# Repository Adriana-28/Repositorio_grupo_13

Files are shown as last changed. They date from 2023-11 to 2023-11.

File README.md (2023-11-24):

<p align="center">
  
</p>

# 👋 Bienvenidos al repositorio del Grupo 13.

- Curso: Fundamentos de Biodiseño
- Línea de investigación: Biomecánica
- Proyecto: "Prótesis de manufactura digital del dedo pulgar"

## ✍️ Profesores del curso

- Renzo Jose Chan Ríos
- Juan Manuel Zuñiga Mamani
- Andrés Rodriguez De Velasco
- Shirley Pahuachon

## 👥 Integrantes del proyecto
  
| Integrantes | Rol del proyecto | Correo electrónico | Foto  |
| :---: | :---: | :---: | :-----: |
| Garcia Reyes Salet Carelis | Coordinadora de investigación  | salet.garcia@upch.pe | <image align="center;" style="borde-radius: 50%;" width="90px;" height="120px;" src="https://github.com/Adriana-28/Repositorio_grupo_13/blob/main/Im%C3%A1genes/WhatsApp%20Image%202023-09-21%20at%2022.54.08.jpeg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">
| Cerna Quispe Alessia Mercedes | Coordinadora de página web  | alessia.cerna@upch.pe | <image align="center;" style="border-radius: 50%;" width="90px;" src ="https://github.com/Adriana-28/Repositorio_grupo_13/blob/main/Im%C3%A1genes/Foto%20Alessia.jpeg?raw=true"> |
| Quispe Gomez Adriana Patricia  | Coordinadora de impresión 3D | adriana.quispe@upch.pe | <image align="center;" width="90px;" src="https://github.com/Adriana-28/Repositorio_grupo_13/blob/main/Im%C3%A1genes/WhatsApp%20Image%202023-09-21%20at%2013.15.54.jpeg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" >
| Panez Cuizano Rafael Alonso | Coordinador de programación | rafael.panez@upch.pe | <image align="center;" style="borde-radius: 50%;" width="90px;" height="120px;" src="https://github.com/Adriana-28/Repositorio_grupo_13/blob/main/Im%C3%A1genes/WhatsApp%20Image%202023-09-21%20at%2022.51.50.jpeg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">
| Munayco Saravia Diego Fabrizio | Coordinador de diseño 3D | diego.munayco@upch.pe | <image align="center;" style="borde-radius: 50%;" width="90px;" src="https://github.com/Adriana-28/Repositorio_grupo_13/blob/main/Im%C3%A1genes/WhatsApp%20Image%202023-09-21%20at%2020.53.01.jpeg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">
| Peralta Yauyo Franco Pedro Sebastian | Coordinador de electrónica | franco.peralta@upch.pe | <image align="center;" style="borde-radius: 50%;" width="90px;" src="https://github.com/Adriana-28/Repositorio_grupo_13/blob/main/Im%C3%A1genes/WhatsApp%20Image%202023-09-21%20at%2022.50.15.jpeg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">

## Contexto

Las lesiones de la mano representan el 12% de todas las lesiones traumáticas en EE.UU., muchas de las cuales consisten en amputaciones traumáticas de los dedos. En 2022, en Estados Unidos se produjeron más de 3.300 amputaciones del pulgar, las cuales se asocian con preocupaciones sociales para el paciente, deterioro funcional y considerables consecuencias económicas para la comunidad atribuidas al absentismo del paciente y a la pérdida de empleo [1]. Esto debido a que el pulgar representa alrededor del 40% de la función de la mano; por lo tanto, perderlo supondría importantes costes médicos, hospitalarios y sociales [2].
En Brasil, este tipo de lesiones son más frecuentes en hombres de entre 20 y 45 años. En términos de prevalencia, la amputación del dedo índice es la más frecuente, con un 28%, seguida del dedo corazón, con un 24%, el anular, con un 21%, el meñique, con un 14%, y el pulgar, con un 13%.” [3].

En Perú, el Instituto Nacional de Rehabilitación define a las limitaciones de la destreza como problemas que se presentan en actividades que se realizan con las manos y dedos, como manipular, abrir y cerrar puertas o ventanas [4], asimismo, el Consejo Nacional para la Integración de la Persona con Discapacidad, informó que el 80,6% de las personas inscritas en el Registro Nacional de la Persona con Discapacidad presenta limitaciones de la destreza [5]. A partir de lo anterior, se puede identificar la relevancia del porcentaje de personas que no pueden realizar actividades cotidianas, incluso la preocupación de estas cifras aumenta, pues el ministerio de Trabajo y Promoción del Empleo a través de "Notificaciones de accidentes de trabajo, incidentes peligrosos y enfermedades ocupacionales" reporta, hasta mayo del 2023, un total de 81 casos de amputaciones por accidentes de trabajo [Tabla 1] y, en promedio, el 16,62% fueron accidentes en los cuales, los dedos de la mano fueron afectados [Tabla 2]. 

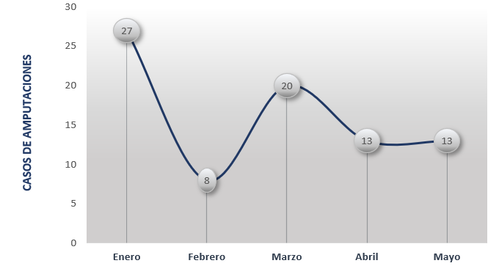
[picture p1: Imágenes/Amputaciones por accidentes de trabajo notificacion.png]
  

| Meses |  Enero  | Febrero | Marzo  | Abril | Mayo |
| :---: | :---: | :---: | :---: | :---: | :---: |
|  Cantidad de amputaciones  | 27  | 8 | 20 | 13  |  13 |

> Tabla 1. Notificaciones de amputaciones por accidentes de trabajo 2023. Fuente: Ministerio de Trabajo y Promoción del Empleo [18].

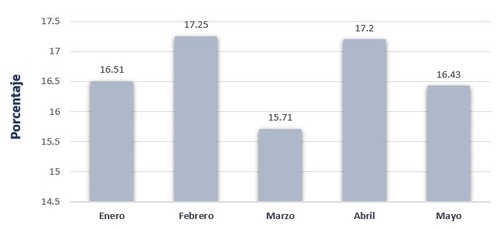
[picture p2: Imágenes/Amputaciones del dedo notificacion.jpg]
  

| Meses |  Enero  | Febrero | Marzo  | Abril | Mayo |
| :---: | :---: | :---: | :---: | :---: | :---: |
|  Porcentaje  |  16.51  |  17.25 |  15.71  |  17.2  |  16.43 |

> Tabla 2. Notificaciones del porcentaje de amputaciones de dedo de la mano 2023. Fuente: Ministerio de Trabajo y Promoción del Empleo [18].

## **👍 Anatomía del pulgar**

La anatomía del dedo pulgar presenta dos músculos principales:

- Dedo extensor largo: El músculo extensor largo del pulgar es crucial para realizar varios movimientos en la mano y el antebrazo. Extiende y abduce el pulgar, ayuda en la aducción, y en ocasiones contribuye a la supinación. Su función es esencial para actividades que requieren movimientos precisos de la mano y el pulgar. 

- Dedo extensor corto: El músculo oponente del pulgar es responsable de realizar movimientos complejos del pulgar conocidos como "oposición". En estos movimientos, el primer metacarpiano se desplaza hacia adelante y hacia el centro en un arco que involucra abducción, rotación medial, flexión y abducción del pulgar en la articulación carpometacarpiana. Esto es fundamental ya que permite que la yema del pulgar pueda tocarse con la yema de los demás dedos, lo que habilita la ejecución de acciones precisas con la mano. 

Los músculos interóseos dorsales tienen la función de abducir los dedos índice, corazón y anular. El primer músculo interóseo dorsal es responsable de rotar el índice en la articulación metacarpo-falángica y ocasionalmente colabora con el músculo aductor del pulgar en la aducción del pulgar. Debido a sus inserciones en la expansión dorsal de los dedos, estos músculos, al igual que los músculos interóseos palmares, ayudan a los músculos lumbricales a facilitar los movimientos de flexión y extensión en las articulaciones metacarpofalángicas e interfalángicas de los dedos. [6]

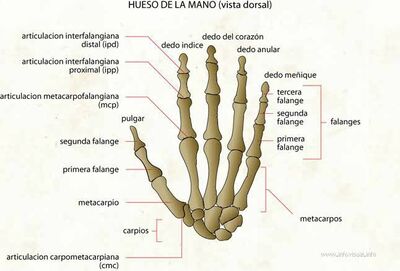
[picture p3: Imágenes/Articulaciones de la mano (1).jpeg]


> Figura 1. Huesos y articulaciones de la mano. Fuente: Rehabilitation of the Hand and Upper Extremity [6].

Según el Departamento de Ortopedia y Traumatología del Hospital Clínico La Florida, Santiago, Chile, la importancia del dedo pulgares que al estar en posición de oposición nos permite realizar distintos tipos de pinza, como las pinzas bidigitales por oposición del pulgar con la parte terminal, subterminal o subterminolateral de los dedos, pinzas pluridigitales terminoterminal o pinza digitopalmar o palmar cilíndrica entre otras. La amputación del pulgar repercute muy negativamente en la función de la mano afectando hasta en un 40-50% y disminuyendo en un 20% la fuerza de puño y pinza. Para obtener un pulgar funcional se requiere que este sea sensible y que sea oponible, y para esto es fundamental que sea estable, fuerte y móvil y además preservar su largo, al menos distal a la parte proximal de la articulación interfalángica [7]

------------

## ✋ Agarres de la mano

Un agarre es toda posición estática de la mano con un objeto que puede ser sujetado firmemente por esta [8]. Se han clasificado alrededor de 16-17 agarres específicos de la mano [9]. Se pueden distinguir alrededor de cuatro categorías generales: [10]

- Poder: Utiliza la mano y los dedos en forma de empuñadura incrementando así la fuerza del agarre en un objeto.
- Precisión:  Involucra el uso del dedo pulgar y la yema de los dedos restantes. Ayuda a manipular objetos de forma exacta.  
- Intermedio: Agarre donde se emplea el dedo índice, pulgar y de apoyo la palma de la mano. Comprenden acciones que necesitan poder y precisión.  
- No prensil: Agarre de objetos sin involucrar la manipulación de los dedos en forma prensil.

Existen 6-9 agarres aproximadamente se utilizan para cerca del 80% de las actividades de la vida diaria e industrial [9] [11]. En general, incluyen variaciones de movimientos como los siguientes: Agarre cilíndrico, agarre intermedio, agarre de gancho, pinza de dos dedos, pinza lateral, pinza de tres dedos, agarre no prensil, agarre lumbrical, agarre oblicuo y agarre intermedio de poder-precisión representan alrededor de 97% variaciones de agarres de la mano encontradas. [12] [9]

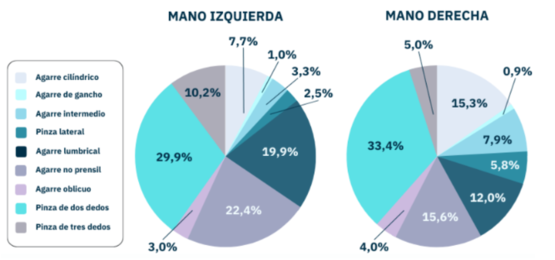
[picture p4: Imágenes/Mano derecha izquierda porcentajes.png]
 
 
> Figura 2. Porcentaje de los tipos de agarres de la mano derecha e izquierda. Fuente: Relevance of grasp types to assess functionality for personal autonomy [12].

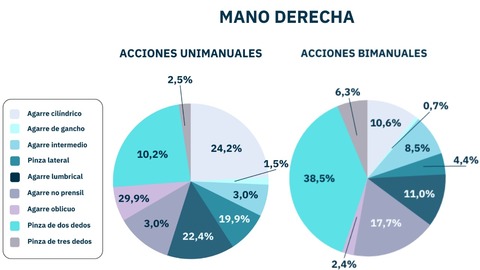
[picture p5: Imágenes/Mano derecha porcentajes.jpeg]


> Figura 3. Porcentaje de las acciones unimanuales y bimanuales de la mano derecha. Fuente: Relevance of grasp types to assess functionality for personal autonomy [12].

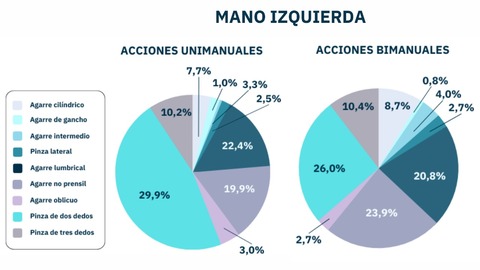
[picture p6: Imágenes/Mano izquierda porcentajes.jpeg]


> Figura 4. Porcentaje de las acciones unimanuales y bimanuales de la mano izquierda. Fuente: Relevance of grasp types to assess functionality for personal autonomy [12].

Siendo el movimiento de pinza de dos dedos el de mayor frecuencia. Cabe indicar que el estudio seleccionó alrededor de 128 tareas, que incluyen áreas como movilidad, comunicación, autocuidado, vida social y actividades domésticas. 

## ¿Cuál es la problemática?

¿Cómo podríamos mejorar el movimiento de pinza en una prótesis 3D del dedo pulgar?

## 💡 Propuesta de solución:

“Prótesis 3D de dedo pulgar con micromotores y componentes para utilizar señales mioeléctricas de músculos cercanos y realizar un agarre de pinza más preciso.”

## Propuesta de valor

El elastómero es uno de los componentes principales que diferencian a nuestro dedo protésico de los otros presentes en el mercado, ya que brindará flexibilidad al momento de generar el agarre pinza, asimismo, los resortes brindan la función de flexión cuando los hilos tensores se muevan debido a la rotación de los servomotores y genera el retorno del dedo a su estado inicial.

## Conoce más acerca de nuestro proyecto

[**Repositorio grupo 13**](https://github.com/Adriana-28/Repositorio_grupo_13/blob/main/Documentaci%C3%B3n/Entregables/ENTREGABLES.md)

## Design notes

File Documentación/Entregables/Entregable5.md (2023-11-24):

# Quinto entregable

## Modelado 3D

[**Link del modelado de la prótesis en OnShape**](https://cad.onshape.com/documents/16cc39156ec121ca3a5e2af5/w/de0ad5fc317e40029288b729/e/4e24d986928bb4f646aaed63)

### Dedo pulgar

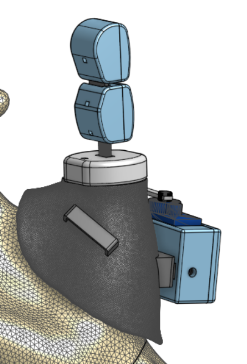
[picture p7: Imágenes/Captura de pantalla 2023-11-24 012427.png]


#### Planos

[**Planos del dedo pulgar en OnShape**](https://cad.onshape.com/documents/16cc39156ec121ca3a5e2af5/w/de0ad5fc317e40029288b729/e/6d90e9a6181cf063c8d92964)

### Case de los servomotores

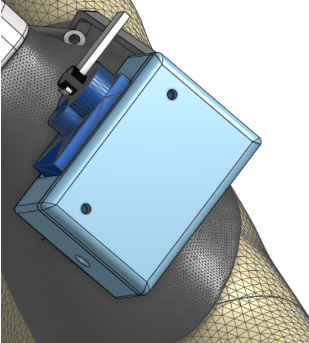
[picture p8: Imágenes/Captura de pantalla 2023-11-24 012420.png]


#### Planos

[**Case de los servomotores**](https://github.com/Adriana-28/Repositorio_grupo_13/blob/main/Im%C3%A1genes/WhatsApp%20Image%202023-11-03%20at%2002.50.40.jpeg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)

### Case del sensor EMG

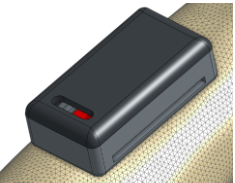
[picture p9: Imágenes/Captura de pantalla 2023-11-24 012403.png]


#### Planos

[**Case del sensor en OnShape**](https://github.com/Adriana-28/Repositorio_grupo_13/blob/main/Im%C3%A1genes/WhatsApp%20Image%202023-11-03%20at%2002.51.05.jpeg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)

### Caja de los componentes

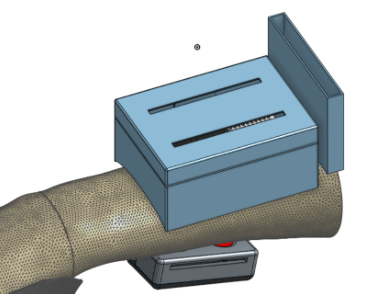
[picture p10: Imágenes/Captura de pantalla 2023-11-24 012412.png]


#### Planos

[**Caja de los componentes**](https://github.com/Adriana-28/Repositorio_grupo_13/blob/main/Im%C3%A1genes/WhatsApp%20Image%202023-11-03%20at%2002.50.23.jpeg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)

## Esquema electrónico

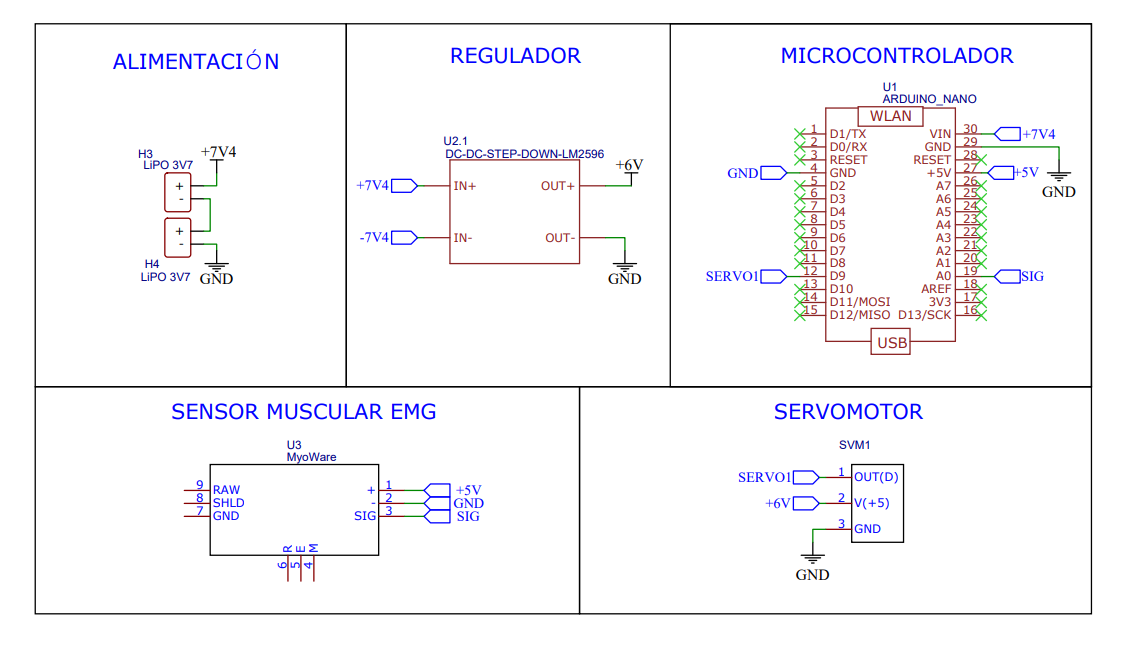
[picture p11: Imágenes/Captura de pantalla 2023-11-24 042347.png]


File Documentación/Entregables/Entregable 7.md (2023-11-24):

# Séptimo entregable

## Código del proyecto

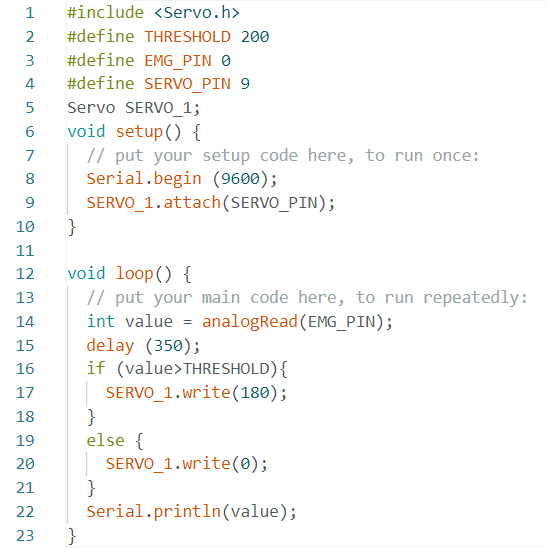
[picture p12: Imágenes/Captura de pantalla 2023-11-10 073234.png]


**- Descripción del código:**

Se demuestra un funcionamiento óptimo del código Arduino. Inicia mediante la instalación de la librería Servo y la creación de variables globales [THRESHOLD,EMG_PIN,SERVO_PIN,SERPO_PIN2]. Luego de la activación del comando serial, conectamos los dos servomotores con sus respectivos pines analogicos, y mediante la función analogRead obtenemos los valores de las señales musculares detectadas por el sensor EMG. Finalmente, mediante una estructura condicional y la magnitud del valor obtenido ejecutamos el movimiento mediante los servomotores sea 180° cuando se ejerce presión y 0° cuando el músculo se encuentra relajado, obteniendo al mismo tiempo la lectura de la señal. 

## Lista de módulos identificados

**Lista de componentes presentes en el funcionamiento del código:**

- Módulo del Sensor EMG:
  
En este caso, este dispositivo cumple la función de monitorear las señales eléctricas de origen muscular, cumple el proceso de amplificar y filtrar para luego ser receptado por algún procesador [Arduino]. Esto se lleva a cabo mediante la lectura del valor analogica de la señal correspondiente al sensor EMG, esto apoyado de los electrodos, el cual al obtener un valor brindaría la acción necesaria para desencadenar el funcionamiento del servomotor y la lectura del EMG, dentro de ciertos parámetros que dependen netamente de la fuerza ejercida por el usuario.

- Módulo de los Servomotores:
  
Identificamos este dispositivo como una alternativa de mecanismo de movimiento, siendo más específicos, de rotación en un rango predeterminado, usualmente entre los 0-180 grados los cuales son utilizados en aplicaciones que requieran precisión y control. La biblioteca Servo nos brinda mayor facilidad mediante la implementación  de señales PWM [Modulación por ancho de pulso], y en nuestro caso dependiente de la señal recibida por el módulo anteriormente mencionado, afectará el rango del movimiento deseado. En este caso al mantener el músculo relajado el servomotor rotara en una posición equivalente a 0 grados y en caso detecte algún esfuerzo muscular generado por el usuario, el servomotor inmediatamente modificara su rango de posición a 180 grados aproximadamente.

## Funcionamiento del circuito con sensor EMG

[**Video del funcionamiento del circuito**](https://drive.google.com/drive/folders/12zblGr60froh0Lr7Ek2Yj1X8CRKrDT_y?usp=drive_link)

Descripción: Se muestra un correcto funcionamiento del circuito. Se utiliza una hoja de papel para la simulación de una superficie y verificar que esta se doble con la programación del circuito. El código corre en el arduino y el sensor EMG detecta las señales y adicionalmente las filtra. Luego, el arduino procesa los datos y envía la señal para que los servomotores giren acorde a lo indicado en el código. 

## Pruebas de prototipo

Debido a las características de nuestro producto, hemos decidido hacer pruebas múltiples con 3 tipos de elastómeros que varían en flexibilidad; sin embargo, todos son del mismo color y están hechos de TPU:

Elastómeros a utilizar:

- Elastómero 1: 2 líneas de pared, no tiene infill porque con esas líneas cubre todo debido a las dimensiones pequeñas de la pieza. Poco flexible. 

- Elastómero 2: 1 línea de pared y 0% de infill. Bastante flexible.

- Elastómero 3: 1 línea de pared y 15% de infill. Flexibilidad intermedia.

  [Vídeo de las pruebas de prototipo](https://drive.google.com/drive/folders/12zblGr60froh0Lr7Ek2Yj1X8CRKrDT_y?usp=drive_link)

|Tipo de elastómero| Resultado |
| :--: | :---: |
|Elastómero 1| Se requiere mucha fuerza para deformarlo y movilizar la prótesis. No se aprecia el movimiento de la falange distal. |
|Elastómero 2 |Se requiere fuerza media para la deformación, se muestra movimiento de la falange distal. El elastómero regresa a su posición original de manera suave. |
| Elastómero 3 | La falange distal presenta un movimiento completo, se muestra una mejor flexibilidad de la prótesis. El elastómero regresa a su posición original de manera rápida.|  

## Prueba con el 95% de las partes

[Vídeo del prototipo 95%](https://drive.google.com/drive/folders/12zblGr60froh0Lr7Ek2Yj1X8CRKrDT_y?usp=drive_link)

- Descripción: El circuito tracciona con las señales mioeléctricas enviadas y el hilo se tensa por los servomotores. Con ello se contrae el elastómero y se estiran los resortes, para que al final de la acción regresen a su forma original. Este video ha sido hecho con el elastómero N, los elegido para el prototipo final. 

## Retos y limitaciones

### Circuito:

**Retos durante la prueba de prototipado:**

 | Reto | Solución |
 | :--: | :--: |
  |Compactar el circuito lo más pequeño posible | Utilizar piezas pequeñas para que no sea pesado el circuito |

  **Limitaciones durante la prueba de prototipado:**

| Limitaciones | Solución |
 | :--: | :--: |
| Se tiene que trabajar con una cantidad de espacio pequeña debido a las dimensiones del brazo humano promedio  | Minimizar en el desorden del circuito, teniendo un diseño compacto para el espacio a utilizar |
| Los componentes son de baja calidad y no siempre tienen precisión | Al tener un buen circuito se tratara que los componentes trabajen de una correcta forma |

### Software

**Retos durante la prueba de prototipado:**

 | Reto | Solución |
  | :--: | :--: |
  | Lograr una mejor filtración de las señales musculares |Añadir un código extra para mejorar la filtración de señal.  |
| El electrodo no detecta las señales del músculo. | Utilizar nuevos electrodos de manera constante y/o buscar electrodos más eficaces. |

  **Limitaciones durante la prueba de prototipado:**
  
| Limitaciones | Solución |
 | :--: | :--: |
|El Arduino nano posee defectos de fábrica que aparecen cada cierto tiempo. | Anotar las descripciones de error e intercambiar cables o drivers de acuerdo al problema. En última instancia, comprar un nuevo Arduino nano. |
|Las señales musculares siempre tienen interferencias. | Mejorar la filtración de las señales musculares en el Arduino. |

### Manufactura digital

**Retos durante la prueba de prototipado:**

 | Reto | Solución |
  | :--: | :--: |
  | La impresión no presente ningún desperfecto por parte de la impresora | Tener parámetros fijos para una correcta impresión |
| Eliminar los soportes de manera adecuada | Tener una buena colocación de soportes en la impresión para evitar daños en la estructura de la pieza |

  **Limitaciones durante la prueba de prototipado:**

| Limitaciones | Solución |
 | :--: | :--: |
| Resistencia y durabilidad de las impresiones debido al material | Tener un buen material de impresión |
| Los detalles pequeños de las piezas pueden no aparecer debido a los límites de las impresoras 3D | Cuidar esos detalles de la impresión con un buen parámetro para evitar daños.|
| Es posible que ciertas medidas planteadas en el modelado no lleguen a tener la misma medida en la vida real por un margen de error pequeño | Tratar de calibrar correctamente la impresora para evitar mucho margen de error |

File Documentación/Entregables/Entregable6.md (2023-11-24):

# Sexto entregable

## Diagrama de flujo del arduino

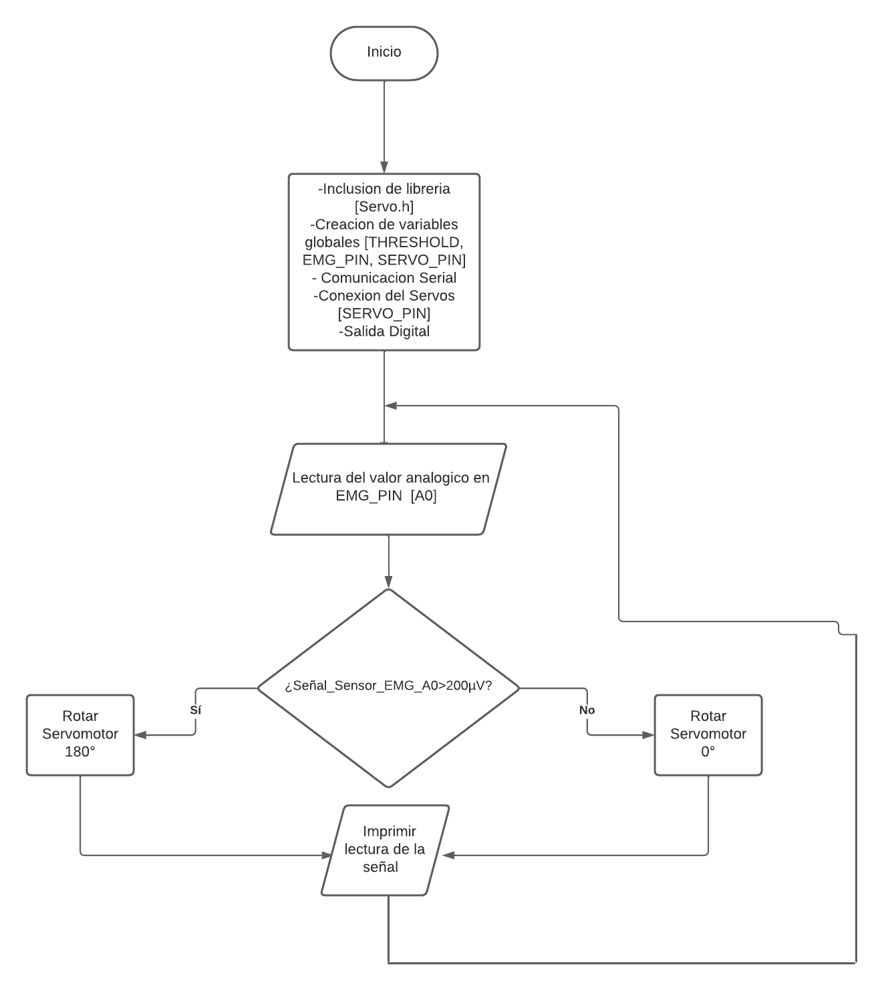
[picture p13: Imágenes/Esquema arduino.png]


## Código del arduino

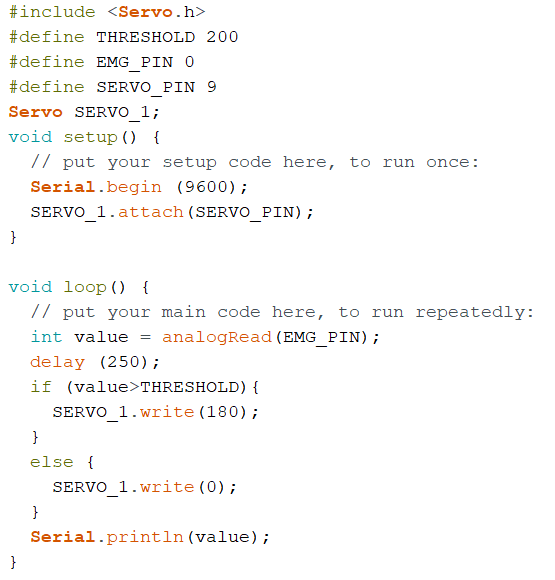
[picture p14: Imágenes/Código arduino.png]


## Ensamblado de la prótesis y componentes

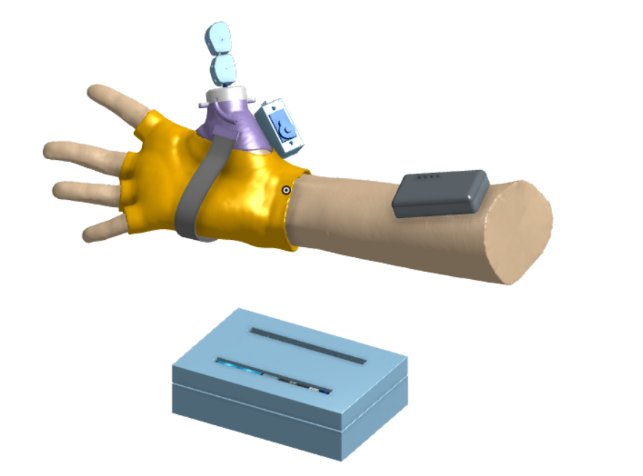
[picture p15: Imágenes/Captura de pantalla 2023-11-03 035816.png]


[**Modificación del modelado en OnShape**](https://cad.onshape.com/documents/16cc39156ec121ca3a5e2af5/w/de0ad5fc317e40029288b729/e/0a8b8b493f9f543559a09a7c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)

[**Video del funcionamiento del circuito**](https://drive.google.com/drive/folders/12zblGr60froh0Lr7Ek2Yj1X8CRKrDT_y?usp=drive_link)

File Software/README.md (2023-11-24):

# Descripción

## Explicación de la amplificación de las señales:

La electromiografía consiste en el proceso de detección, amplificación y filtración de señales mioeléctricas, mediante el monitoreo del potencial eléctrico  debido al intercambio de iones de membranas pertenecientes a fibras musculares por ejercer contracciones.

Con el fin de realizar el registro y análisis de actividad eléctrica, se utilizan tres electrodos de superficie [No invasivos], siendo más específicos los húmedos, los cuales presentan materiales con alta conductividad, sustancias electrolíticas por ejemplo Ag/AgCl, donde se optimiza la intensidad de corriente y usualmente poseen un recubrimiento de gel conductor que garantiza mayor durabilidad. 

Al obtener las señales, identificamos que estas presentan debilidad y amplitudes de magnitudes bajas, las cuales son difíciles de captar, por ello se opta por un amplificador de tipo CMOS integrado dentro del sensor EMG.

## Explicación amplificador CMOS: 
El amplificador semiconductor de óxido metálico complementario, usualmente incorporado en circuitos integrados, posee la función principal de, al momento de detectar las señales mioeléctricas, incrementar la amplitud de la señal con el fin de facilitar la transmisión de información y que estas sean detectadas efectivamente.

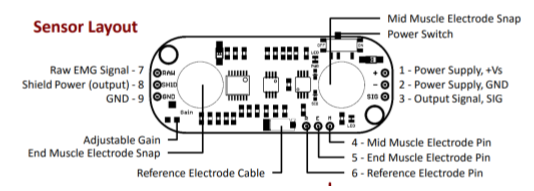
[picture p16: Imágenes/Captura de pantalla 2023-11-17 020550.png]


> Figura 1.

## Concepto de Electromiografía
Es un aparato que dentro de sus estructura consiste de 3 amplificadores operacionales [OPAMP].
Cumple la función de amplificar las señales que presentan medidas de voltaje muy débiles, como es el caso del cuerpo humano. La representación de estas señales se les conoce como PAs musculares y el potenciador de amplificación se encuentra en un rango de 50- 250K veces.

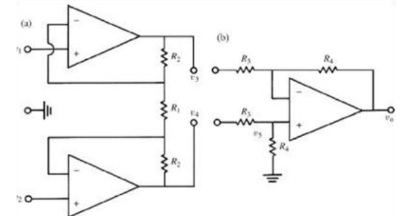
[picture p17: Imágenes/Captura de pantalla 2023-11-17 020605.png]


**Recomendación:** Administrar correctamente la magnitud de ganancia del amplificador para evitar una posible saturación, esto debido a diversas consecuencias como:
Degradación de la vida útil del amplificador
Señales presentan distorsiones armónicas, distorsiones e interferencias visualizadas en la función. 
El periodo de recuperación del amplificador es demasiado tardío.

Segunda Parte:

Parámetros de la curva de la señal mioeléctrica: Voltaje, tiempo.

Dentro de la función registrada en función del tiempo, obtenemos los valores de la señal registrada. 
Estas señales son captadas cuando se ejerce cierta actividad eléctrica producida por algún grupo muscular presente. Cuando se generan los picos dentro de la función, indica el incremento de intensidad y presión de la contracción del músculo en un periodo específico

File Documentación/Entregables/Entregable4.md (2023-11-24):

# Cuarto entregable

## 🥇 Proyecto preliminar 1

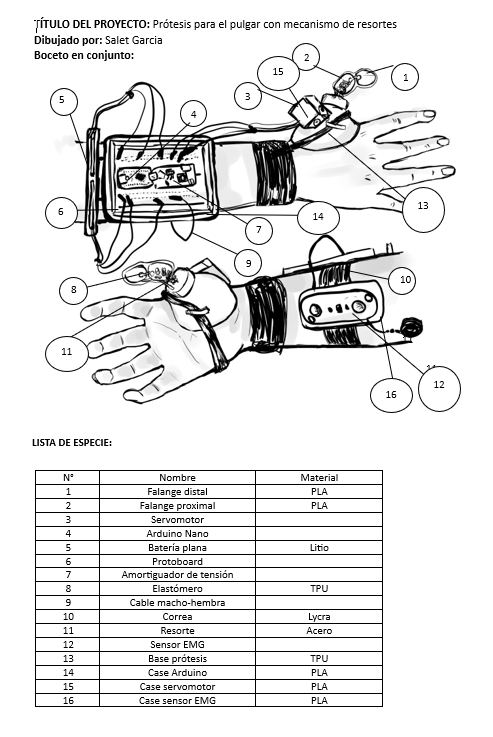
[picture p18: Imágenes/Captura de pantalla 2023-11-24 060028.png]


## 🥈 Proyecto preliminar 2

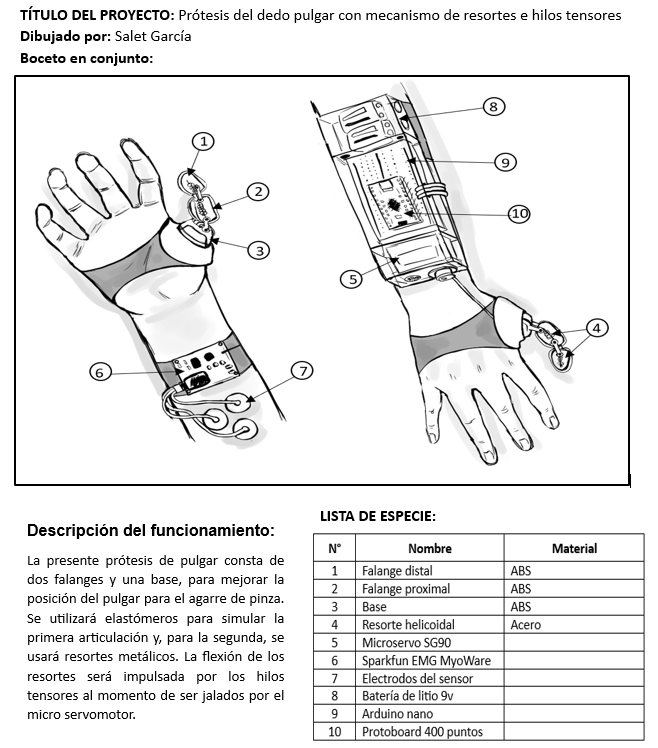
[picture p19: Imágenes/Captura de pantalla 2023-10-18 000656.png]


## 🥉 Proyecto preliminar 3

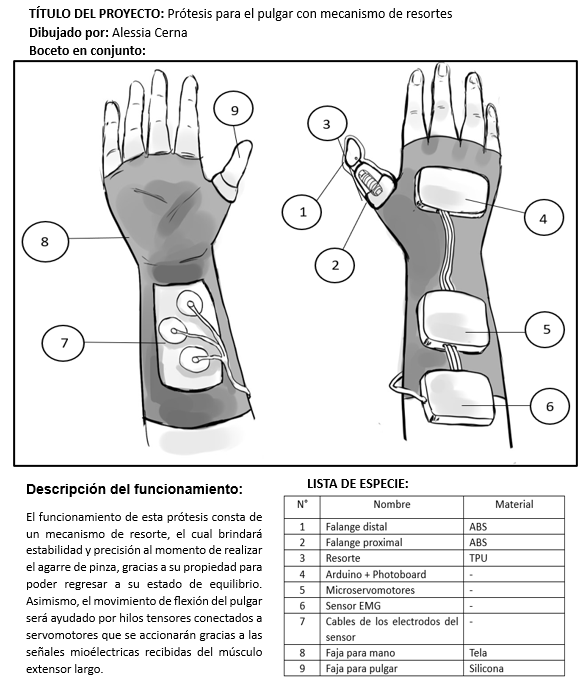
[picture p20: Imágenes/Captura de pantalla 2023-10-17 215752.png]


## Proyecto preliminar 1 (variación)

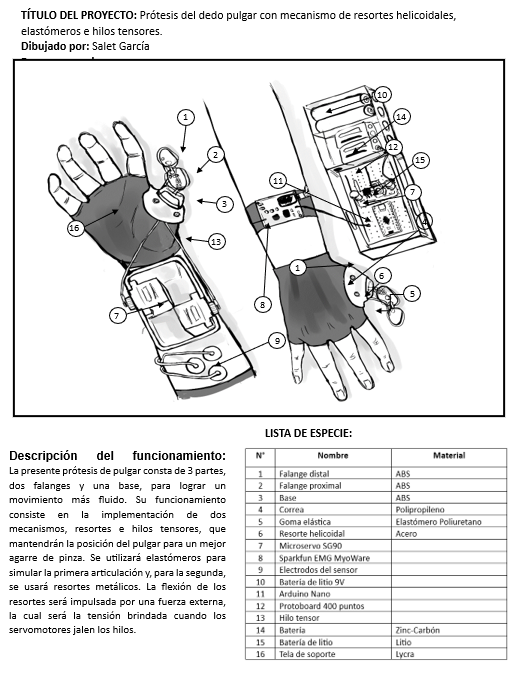
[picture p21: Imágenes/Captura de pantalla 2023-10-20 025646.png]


## Tablas de Valoración Técnica y Económica:

### Matriz de evaluación - evaluación técnica

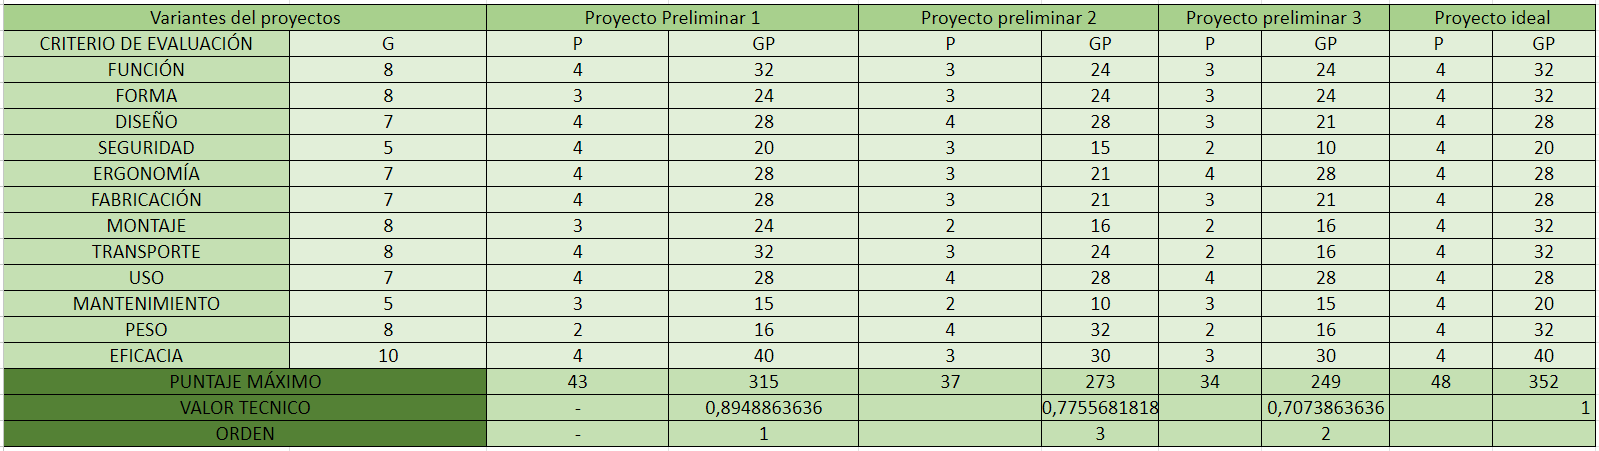
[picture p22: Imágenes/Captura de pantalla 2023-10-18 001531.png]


### Matriz de evaluación - evaluación económica
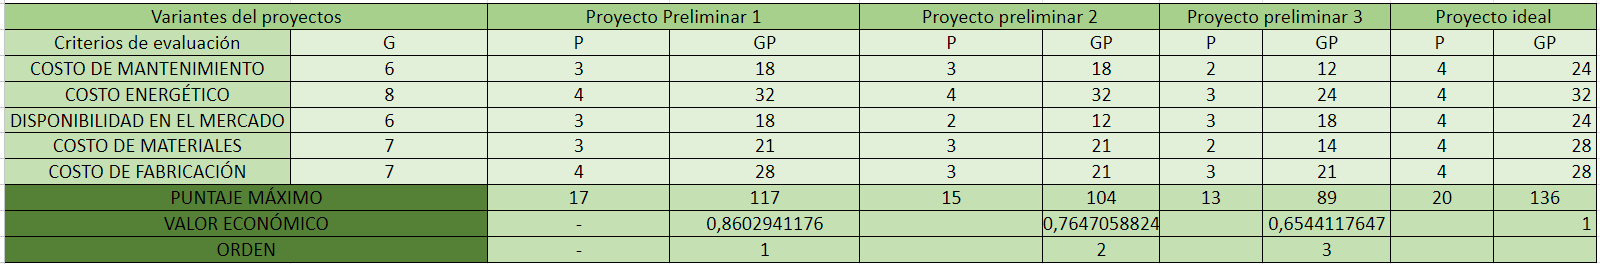
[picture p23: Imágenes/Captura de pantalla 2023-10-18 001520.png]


## Gráfica de evaluación técnico-económica

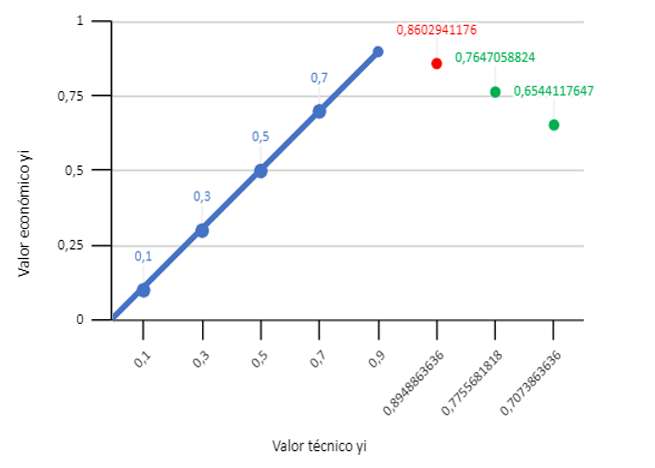
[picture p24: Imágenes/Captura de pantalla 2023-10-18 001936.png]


| | 	xi	| yi|
| :---: | :---: | :---: |
|**PP1**|	**0,8948863636**|	**0,8602941176**|
|PP2	|0,7755681818	|0,7647058824|
|PP3|	0,7073863636	|0,6544117647|

### Conclusiones

De acuerdo a las tablas realizadas, técnica y económica, el proyecto preliminar 1 (PP1) es el más adecuado debido a sus carácterísticas como solución a nuestra problemática.

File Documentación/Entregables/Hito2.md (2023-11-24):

# Hito 2

[Link del PPT](https://www.canva.com/design/DAF06DctvFs/FIjZPL27ln_elTT2GaQDLQ/edit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)

## Modelado 3D

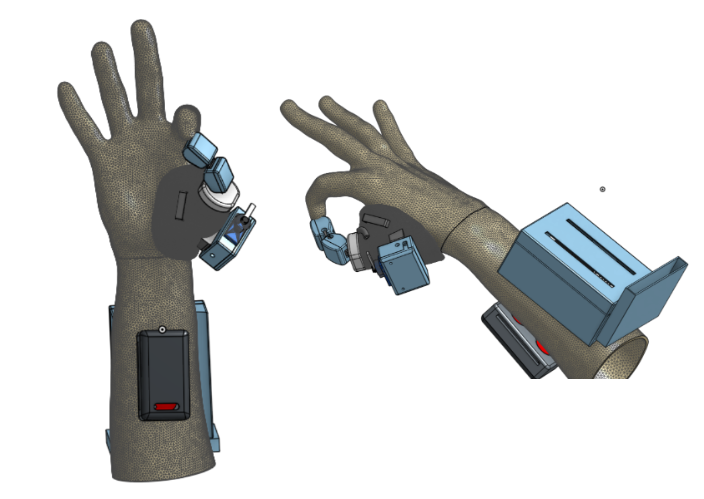
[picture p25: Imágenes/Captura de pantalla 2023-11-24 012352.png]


## Prototipo de la prótesis ensamblada

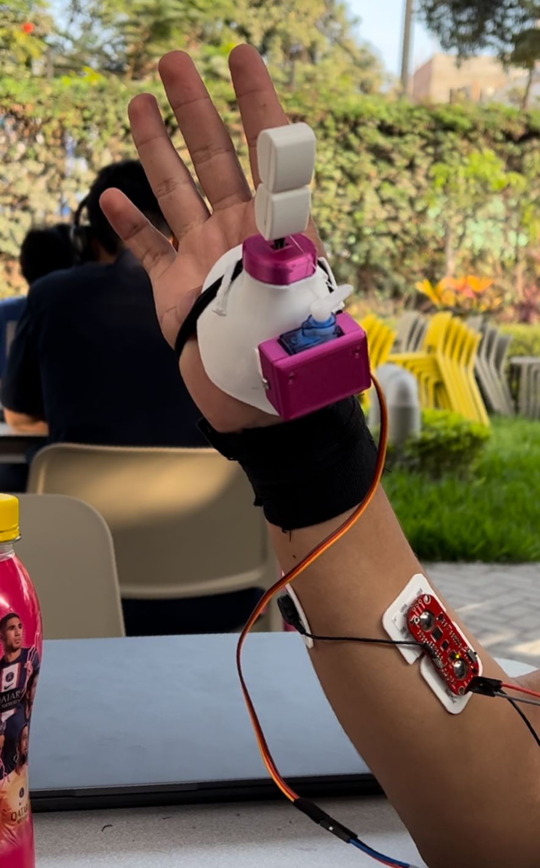
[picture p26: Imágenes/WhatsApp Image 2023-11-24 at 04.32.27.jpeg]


[Link de multimedia](https://drive.google.com/drive/folders/12zblGr60froh0Lr7Ek2Yj1X8CRKrDT_y)

## Diagrama de flujo

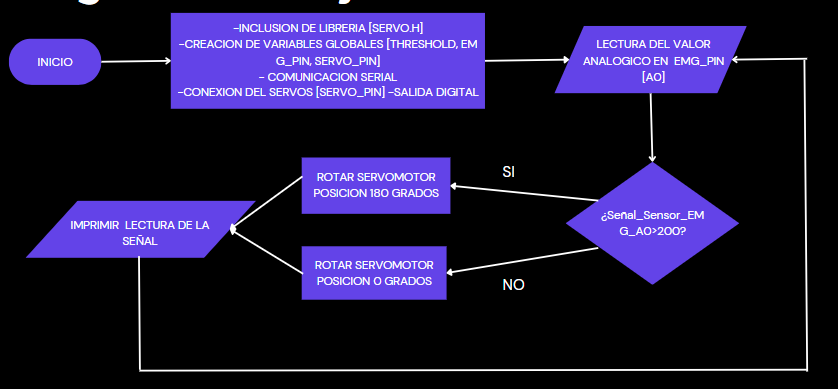
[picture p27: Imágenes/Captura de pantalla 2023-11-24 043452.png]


[Descripción del diagrama de flujo](https://github.com/Adriana-28/Repositorio_grupo_13/blob/main/Software/README.md)

## Código

[Link del código](https://github.com/Adriana-28/Repositorio_grupo_13/blob/main/Software/Codigo_Servomotor1_EMG.ino)

## Análisis cinético de la prótesis

[Registro de señales](https://github.com/Adriana-28/Repositorio_grupo_13/blob/main/Documentaci%C3%B3n/Registros%20mec%C3%A1nico/An%C3%A1lisis.md)

## Presupuesto

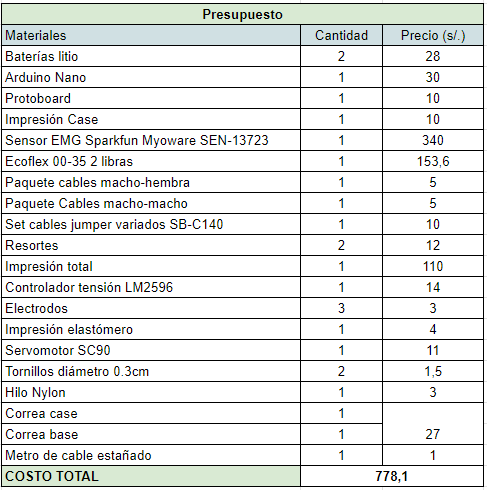
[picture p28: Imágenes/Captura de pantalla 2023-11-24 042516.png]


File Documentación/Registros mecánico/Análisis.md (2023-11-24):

# Análisis

## Gráficas de señales del sensor de fuerza

**Leyendas**

- Elastómero 1: el que tiene la menor propiedad de flexión.
- Elastómero 2: el que tiene más o menos flexión.
- Elastómero 3: el más flexible.

### Elastómero 1

Valor máximo

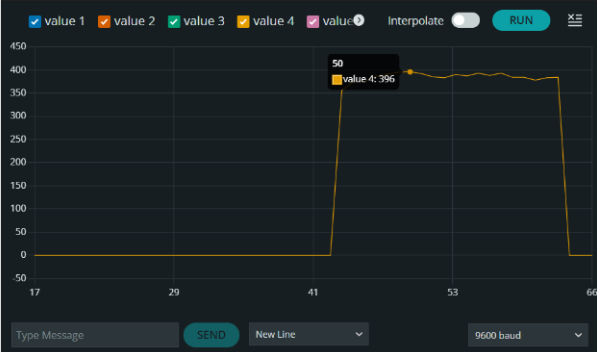
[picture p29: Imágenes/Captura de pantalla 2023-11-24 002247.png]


Valor mínimo

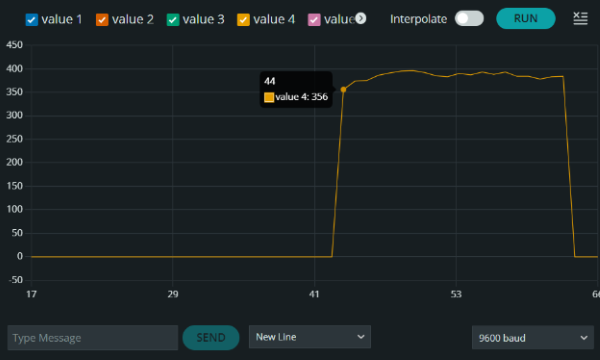
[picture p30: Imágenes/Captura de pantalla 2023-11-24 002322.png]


### Elastómero 2

Valor máximo



Valor mínimo



### Elastómero 3

Valor mínimo



Valor mínimo



## Gráfica de señal de fuerza ejercida por el dedo

Valor máximo



Valor mínimo



## Tabla para la curva de calibración

|Peso (g)| Señal (u.a)|
| :--: | :---: |
|43|79|
|89.8|135|
|113.26|156|
|196.93|214|
|223,5|229|
|272,5|255|
|326,5|280|

Haciendo una curva de calibración con estos datos, obtenemos la siguiente ecuación:
y = 0,688x + 68,16
Teniendo dicha ecuación, con un r2= a 0.974, la pendiente será nuestro número para la conversión, entonces:

- Elastómero 1:
  
396-68,16=0,688x → 327,84/0,688=x →476,51*9,8/1000= **4,67 N**
  
356-68,16=0,688x → 287,84/0,688=x →418,37*9,8/1000= **4,1  N**
  
- Elastómero 2:
  
340-68,16=0,688x → 271,84/0,688=x →395,12*9,8/1000= **3,87 N**
  
307-68,16=0,688x → 238,84/0,688=x→ 347,15*9,8/1000= **3,4 N**
  
- Elastómero 3:
  
283-68,16=0,688x → 214,84/0,688=x →312,27*9,8/1000= **3,6 N**

271-68,16=0,688x → 294,83/0,688=x →294,83*9,8/1000= **2,89 N**
  
- Dedo Normal:
  
878-68,16=0,688x → 1177,09/0,688=x →1710,89*9,8/1000= **16,77 N**
  
415-68,16=0,688x → 346,84/0,688=x →504,13*9,8/1000= **4,94 N**

## Tabla de cosas que sí se pueden agarrar con la prótesis

|OBJETO|¿PUEDE AGARRARLO EN FORMA DE PINZA?| Imagen referencial |
| :--: | :---: | :--: |
|Caja de la silicona| Si|  |
|Plumón de pizarra Faber Castell| Si|  |
|Lapicero|Si| |
|Cargador de Laptop|No|  |

## Pruebas de la prótesis sosteniendo objetos

[Link de multimedia](https://drive.google.com/drive/folders/1ylTTBGORAo1_QkyFgVd90WSjdjrfjHgY)

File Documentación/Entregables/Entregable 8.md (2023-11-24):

# Octavo entregable

## Preguntas previas

- ¿Cuánto tiempo debería durar la batería?
  10.99 horas.

- ¿Los objetos de la prótesis no se resbalaran?
No, esto debido a que se ha bañado la punta y articulaciones del dedo protésico en ecoflex, un tipo de silicona flexible.

- ¿Las dimensiones de la prótesis son las adecuadas?
  Si debido a la forma y tamaño que se asemeja al dedo pulgar

- ¿Es lo suficientemente pequeño para que sea portátil?
 No, debido a que el case donde se ubican los componentes de arduino,regulador y protoboard son ligeramente grandes  

- ¿La prótesis es de fácil comprensión para el paciente?
Sí, pues no es complejo colocarse en el brazo del usuario.

- ¿Qué tan cómodo o amigable con la piel es la prótesis para el paciente?
Es amigable debido al material impreso que estamos utilizando, lo cual hace que el paciente se sienta satisfecho
  
- ¿La prótesis llega a resbalarse de la mano?
No, debido a que utilizamos una correa para sujetar la base al muñón

## Tabla de requerimientos





## Tabla de verificación del proyecto

| Funcionalidad | Cumplimiento |
| :--: | :---: |
|La prótesis que tiene contacto debe tener silicona médica alrededor del paciente. | No |
|El circuito de la prótesis se debe mantener activo  para el correcto funcionamiento del prototipo| Sí |
|La prótesis debe ser capaz de realizar un movimiento de pinza con ángulos correctos sin ayuda externa|Sí |
|El sensor EMG debe detectar la señal mioeléctrica sin complicación alguna a través de su case| Sí|
|La prótesis debe ser lo suficientemente liviana para que el usuario la use con normalidad |Sí |
|El circuito de la prótesis debe ser capaz de obtener y procesar la información hacia los servomotores de manera correcta. |Sí |
|La prótesis debe ocupar el menor espacio posible y ser portátil| Sí|
|La batería debería durar el tiempo suficiente para que el usuario pueda hacer de manera autónoma sus tareas| Sí|
|La prótesis debe tener una silicona en los dedos para evitar el deslice de objetos.| No |

## Cuantificación del movimiento de la prótesis

### Procedimiento: Videos de pruebas

[**Link de los videos de prueba**](https://drive.google.com/drive/folders/12zblGr60froh0Lr7Ek2Yj1X8CRKrDT_y)

### Tabla datos 

- Elastómero 1: Elastómero menos flexible

- Elastómero 2: Elastómero medio flexible

- Elastómero 3: Elastómero más flexible

- Resorte 1: Diámetro 0.2 cm

- Resorte 2: Diámetro 0.3 cm

𝝰: Ángulo entre falange proximal y distal
𝛃: Ángulo entre base y falange proximal







**Variación (%) = (ángulo final - ángulo inicial) / ángulo inicial * 100%**



### Ángulos de movimiento

- Articulación MF: De 0° a 50°
- Articulación IF: De 0° a 80°

### Extensión MF e IF del pulgar

| Músculo | Origen | Inserción |
| :--: | :---: | :--: |
|Extensión MF: Extensor corto propio del pulgar | Radio (superficie posterior) | Pulgar (falange proximal, dorsal)|
|Extensión IF: Extensor largo del pulgar | Cúbito (superficie posterolateral del eje medio), membrana interósea | Pulgar (base de la falange distal)|

> Tabla 1 [1]





## Pruebas para el manejo de prótesis mioeléctricas y el agarre

Para evaluar el desempeño y las funcionalidades de los dos sistemas consideramos 2 evaluaciones estándar, la prueba de Caja y Bloques (BBT) y la Evaluación de la Capacidad de Control Mioeléctrico (ACMC).
La BBT mide la destreza manual bruta unilateral 45 y se utiliza con una amplia gama de poblaciones (es decir, no es específica para prótesis). El usuario debe mover el número máximo de bloques, uno por uno, de un compartimento a otro en 60 s. Repetimos esta acción 3 veces. Para evaluar funcionalidades avanzadas y habilidades de manipulación, incluimos la prueba ACMC. Es la primera evaluación de resultados diseñada específicamente para prótesis mioeléctricas. El ACMC es una evaluación basada en observaciones que mide la capacidad de una persona para operar una prótesis de mano mioeléctrica cuando realiza actividades de la vida cotidiana. La prueba consta de 22 ítems divididos en 4 subsecciones (Agarrar, Reajustar el agarre, Sostener, Soltar) y puntuados en una escala de calificación de 4 puntos por un observador certificado. [2]

## Conclusiones

Según los datos de los ángulos obtenidos se puede evidenciar que el elastómero medio flexible es el que tiene mejores resultados, pues tiene un valor aceptable de flexión y se asemeja más con la flexión de un dedo pulgar real, el cual posee una flexión de hasta 80°, sin dejar de lado sus propiedades de resistencia.
El resorte con mejores resultados es el resorte 2, obteniendo ángulos bastante cercanos a 40°, el cual sería el ideal.

## Bibliografía

[1]  Hislop HJ, Montgomery J. Pruebas funcionales musculares - 6b* ed. Marban Libros; 2001.

[2]  Capsi-Morales P, Piazza C, Catalano MG, Grioli G, Schiavon L, Fiaschi E, et al. Comparison between rigid and soft poly-articulated prosthetic hands in non-expert myo-electric users shows advantages of soft robotics. Sci Rep [Internet]. 2021;11(1). Disponible en: http://dx.doi.org/10.1038/s41598-021-02562-y

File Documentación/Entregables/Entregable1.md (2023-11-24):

# Primer entregable (retroalimentación agregada)

## Contexto

Las lesiones de la mano representan el 12% de todas las lesiones traumáticas en EE.UU., muchas de las cuales consisten en amputaciones traumáticas de los dedos. En 2022, en Estados Unidos se produjeron más de 3.300 amputaciones del pulgar, las cuales se asocian con preocupaciones sociales para el paciente, deterioro funcional y considerables consecuencias económicas para la comunidad atribuidas al absentismo del paciente y a la pérdida de empleo [1]. Esto debido a que el pulgar representa alrededor del 40% de la función de la mano; por lo tanto, perderlo supondría importantes costes médicos, hospitalarios y sociales [2].
En Brasil, este tipo de lesiones son más frecuentes en hombres de entre 20 y 45 años. En términos de prevalencia, la amputación del dedo índice es la más frecuente, con un 28%, seguida del dedo corazón, con un 24%, el anular, con un 21%, el meñique, con un 14%, y el pulgar, con un 13%.” [3].

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

  

| Meses |  Enero  | Febrero | Marzo  | Abril | Mayo |
| :---: | :---: | :---: | :---: | :---: | :---: |
|  Cantidad de amputaciones  | 27  | 8 | 20 | 13  |  13 |

> Tabla 1. Notificaciones de amputaciones por accidentes de trabajo 2023. Fuente: Ministerio de Trabajo y Promoción del Empleo [18].

  

| Meses |  Enero  | Febrero | Marzo  | Abril | Mayo |
| :---: | :---: | :---: | :---: | :---: | :---: |
|  Porcentaje  |  16.51  |  17.25 |  15.71  |  17.2  |  16.43 |

> Tabla 2. Notificaciones del porcentaje de amputaciones de dedo de la mano 2023. Fuente: Ministerio de Trabajo y Promoción del Empleo [18].

------------

### **👍 Anatomía del pulgar**

La anatomía del dedo pulgar presenta dos músculos principales:

- Dedo extensor largo: El músculo extensor largo del pulgar es crucial para realizar varios movimientos en la mano y el antebrazo. Extiende y abduce el pulgar, ayuda en la aducción, y en ocasiones contribuye a la supinación. Su función es esencial para actividades que requieren movimientos precisos de la mano y el pulgar. 

- Dedo extensor corto: El músculo oponente del pulgar es responsable de realizar movimientos complejos del pulgar conocidos como "oposición". En estos movimientos, el primer metacarpiano se desplaza hacia adelante y hacia el centro en un arco que involucra abducción, rotación medial, flexión y abducción del pulgar en la articulación carpometacarpiana. Esto es fundamental ya que permite que la yema del pulgar pueda tocarse con la yema de los demás dedos, lo que habilita la ejecución de acciones precisas con la mano. 

Los músculos interóseos dorsales tienen la función de abducir los dedos índice, corazón y anular. El primer músculo interóseo dorsal es responsable de rotar el índice en la articulación metacarpo-falángica y ocasionalmente colabora con el músculo aductor del pulgar en la aducción del pulgar. Debido a sus inserciones en la expansión dorsal de los dedos, estos músculos, al igual que los músculos interóseos palmares, ayudan a los músculos lumbricales a facilitar los movimientos de flexión y extensión en las articulaciones metacarpofalángicas e interfalángicas de los dedos. [6]



> Figura 1. Huesos y articulaciones de la mano. Fuente: Rehabilitation of the Hand and Upper Extremity [6].

Según el Departamento de Ortopedia y Traumatología del Hospital Clínico La Florida, Santiago, Chile, la importancia del dedo pulgares que al estar en posición de oposición nos permite realizar distintos tipos de pinza, como las pinzas bidigitales por oposición del pulgar con la parte terminal, subterminal o subterminolateral de los dedos, pinzas pluridigitales terminoterminal o pinza digitopalmar o palmar cilíndrica entre otras. La amputación del pulgar repercute muy negativamente en la función de la mano afectando hasta en un 40-50% y disminuyendo en un 20% la fuerza de puño y pinza. Para obtener un pulgar funcional se requiere que este sea sensible y que sea oponible, y para esto es fundamental que sea estable, fuerte y móvil y además preservar su largo, al menos distal a la parte proximal de la articulación interfalángica [7]

------------

### ✋ Agarres de la mano

Un agarre es toda posición estática de la mano con un objeto que puede ser sujetado firmemente por esta [8]. Se han clasificado alrededor de 16-17 agarres específicos de la mano [9]. Se pueden distinguir alrededor de cuatro categorías generales: [10]

- Poder: Utiliza la mano y los dedos en forma de empuñadura incrementando así la fuerza del agarre en un objeto.
- Precisión:  Involucra el uso del dedo pulgar y la yema de los dedos restantes. Ayuda a manipular objetos de forma exacta.  
- Intermedio: Agarre donde se emplea el dedo índice, pulgar y de apoyo la palma de la mano. Comprenden acciones que necesitan poder y precisión.  
- No prensil: Agarre de objetos sin involucrar la manipulación de los dedos en forma prensil.

Existen 6-9 agarres aproximadamente se utilizan para cerca del 80% de las actividades de la vida diaria e industrial [9] [11]. En general, incluyen variaciones de movimientos como los siguientes: Agarre cilíndrico, agarre intermedio, agarre de gancho, pinza de dos dedos, pinza lateral, pinza de tres dedos, agarre no prensil, agarre lumbrical, agarre oblicuo y agarre intermedio de poder-precisión representan alrededor de 97% variaciones de agarres de la mano encontradas. [12] [9]

 
 
> Figura 2. Porcentaje de los tipos de agarres de la mano derecha e izquierda. Fuente: Relevance of grasp types to assess functionality for personal autonomy [12].



> Figura 3. Porcentaje de las acciones unimanuales y bimanuales de la mano derecha. Fuente: Relevance of grasp types to assess functionality for personal autonomy [12].



> Figura 4. Porcentaje de las acciones unimanuales y bimanuales de la mano izquierda. Fuente: Relevance of grasp types to assess functionality for personal autonomy [12].

Siendo el movimiento de pinza de dos dedos el de mayor frecuencia. Cabe indicar que el estudio seleccionó alrededor de 128 tareas, que incluyen áreas como movilidad, comunicación, autocuidado, vida social y actividades domésticas. 

----

## Estado del arte

### Dificultades de los tipos de prótesis de miembro superior

La pérdida de una mano puede afectar significativamente el nivel de autonomía y la capacidad de realizar actividades de la vida diaria, laborales y sociales. Las soluciones protésicas actuales. 
Se realizó un análisis de las necesidades de los usuarios de prótesis de miembro superior y señala los principales aspectos críticos de las soluciones protésicas en los últimos años.
Las prótesis de miembro superior se pueden clasificar en dos categorías principales en función de su funcionamiento: prótesis pasivas (que a su vez se dividen en cosméticas y funcionales) y prótesis activas (dispositivos mioeléctricos y accionados por el cuerpo).

**Prótesis pasivas:** 
Los dispositivos protésicos pasivos se emplean cuando la apariencia física y la comodidad son de máxima prioridad.
Siguen siendo una opción popular para los usuarios a pesar de sus limitaciones funcionales. Son relativamente económicos y tienen un aspecto cosmético y estéticamente agradable. Sin embargo, la funcionalidad se limita a acciones primitivas como empujar, tirar y transportar objetos. Se usan comúnmente en situaciones sociales ya que aumentan la confianza del usuario. Aproximadamente uno de cada tres amputados utiliza una prótesis pasiva de alguna manera.

**Prótesis activas:**

- Dispositivos impulsados por el cuerpo:

Las prótesis de extremidades superiores accionadas por el cuerpo se controlan mediante un arnés que se conecta mediante un cable a otra parte del cuerpo del paciente, como el hombro sano. Son menos susceptibles que las prótesis mioeléctricas a sufrir daños en condiciones volátiles como ambientes corrosivos y húmedos debido a que excluyen baterías o una fuente de energía alternativa. En Estados Unidos, una prótesis de extremidad superior accionada por el cuerpo puede costar aproximadamente 10.000 dólares.
Uno de los principales retos de la ingeniería en el desarrollo de prótesis es, por un lado, integrar actuadores, sensores y componentes electrónicos en una prótesis del mismo tamaño y peso que la mano o extremidad reemplazada y, por otro lado, mejorar la prótesis. control que afecta notablemente a la funcionalidad.

- Dispositivos mioeléctricos:

Las prótesis mioeléctricas de extremidades superiores se alimentan mediante el uso de motores eléctricos con una fuente de energía externa. El movimiento de la articulación se controla mediante la actividad muscular de la extremidad restante. Las señales electromiográficas (EMG) del muñón de la extremidad se detectan mediante electrodos de superficie, se amplifican y luego se procesan mediante un controlador para accionar motores alimentados por baterías que mueven la mano, la muñeca o el codo.
A pesar de los avances funcionales y cosméticos en comparación con las prótesis pasivas y corporales, el costo de los dispositivos mioeléctricos es una barrera que limita el acceso de los usuarios, pues los precios oscilan entre 20.000 y 100.000 dólares. Otro aspecto negativo es que necesitan recargar su batería a diario. La batería puede dañarse debido a factores ambientales como agua y suciedad; los costos de mantenimiento y reparación de los dispositivos son generalmente más altos que los de las alternativas. [13]

#### Abandono de prótesis de miembro superior

| Tipo de dispositivo |  Pasivo  | Impulsado por el cuerpo | Mioeléctricos |
| :---: | :---: | :---: | :---: |
|  Comodidad  |  Temperatura, peso, transpiración, ropa dañada  | Temperatura, peso, transpiración, ropa dañada, malestar general, irritación del arnés, mal encajado, dolor | Temperatura, peso, dolor, malestar general, mal encajado | 
| Funcionalidad | Falta de beneficio funcional, no duradero | Difícil de controlar, no duradero, falta de funcionalidad | Difícil de controlar, velocidad de respuesta lenta, falta de retroalimentación sensorial, poca destreza, no duradero, falta de funcionalidad, demasiado alborotado | 
| Otros |  | Estética  | Estética  | 

>Tabla 3. Motivos del abandono protésico por tipo de dispositivo. Fuente: Comfort and function remain key factors in upper limb prosthetic abandonment: findings of a scoping review [14].

En los nueve estudios incluidos en esta revisión, tanto la comodidad general como la función se mencionaron sistemáticamente como razones principales asociadas con el abandono del dispositivo protésico. Estos factores en cada uno de los tipos de dispositivos incluidos, y en las tres décadas de estudios incluidos en esta revisión.
Aunque la funcionalidad se ha convertido en uno de los focos de investigación de los últimos diez años, la comodidad de las prótesis no debe descartarse en el diseño y desarrollo de futuras prótesis de miembro superior. [14]

### Acerca de las prótesis de dedos

Las amputaciones parciales de la mano son la amputación más común de las extremidades superiores. Como los dedos, el pulgar y las regiones transmetacarpianas pueden verse afectados, las opciones de tratamiento para restaurar la forma y su función son esenciales para aliviar las cargas que pesan sobre los individuos y las comunidades. Gracias a los avances recientes en ingeniería, los dispositivos protésicos están cada vez más disponibles y brindan soluciones sencillas para las personas con amputación parcial de la mano. [15]

#### Características importantes acerca del funcionamiento de las prótesis de dedos

Desde el punto de vista de los amputados, una prótesis de mano adecuada tiene diferentes características, como parecido con la anatomía de la mano humana, bajo peso, bajo costo y alta funcionalidad (capacidad de realizar trabajos prácticos patrones de agarre, particularmente agarre de potencia y precisión). 

Para evaluar los dedos de las prótesis de mano, debemos tomar en cuenta diferentes aspectos de los mecanismos asociados a su funcionamiento. A la luz de los puntos destacados en la literatura relevante, se encontraron criterios importantes para la descripción de una estructura de dedo. Con base en estos criterios, evaluamos el desempeño de los mecanismos de los dedos de manos protésicas. 
A continuación, definiremos y discutiremos completamente la importancia de algunos criterios importantes para las prótesis de dedos, categorizados en agarre y aspectos físicos.

Los grados de libertad (DOF) de un sistema mecánico es el número de parámetros independientes que definen su configuración o estado.

### Características del agarre

- Movimiento natural:
En varias manos protésicas, los mecanismos de los dedos se desarrollan basándose en una característica antropomórfica que es el movimiento natural de la mano humana. 
El movimiento natural se considera como la preformación de las falanges mediante una relación lineal antes de alcanzar un objeto. 
La falta de movimiento natural puede provocar fallas en el agarre. Para ilustrar, si un objeto se desliza sobre una falange, el movimiento de la más falanges, ejecutando un movimiento natural, evitarían el colapso del agarre.



>Figura 5. Comparación de no preformado (a) y preformado (b). Fuente: A review on linkage-driven finger mechanisms of prosthetic hands and evaluation of the performance criteria [16]

- Adaptación de forma:
Los mecanismos de adaptación de la forma se han utilizado notablemente en muchas de las prótesis de manos investigadas. La estabilidad de algunos de los patrones de comprensión como la comprensión del poder pueden mejorarse con esta característica. Esta característica se clasifica en dos aspectos diferentes, incluyendo manos que se adaptan a la forma y mecanismos de dedos que se adaptan a la forma. 

En el primer tipo, al reducir el número de actuadores, dos o más dedos de una mano artificial son accionados por un solo actuador. De hecho, una vez que un dedo toca un objeto, los movimientos de los otros dedos continúan hasta el final del proceso de agarre. En el segundo tipo, que se considera en el presente estudio, la adaptabilidad de la forma se define como los movimientos individuales de las falanges. 



> Figura 6. Modo de agarre adaptable a la forma de un dedo de dos falanges. (a) primera etapa (b) contacto inicial (c) agarre completo. Fuente: A review on linkage-driven finger mechanisms of prosthetic hands and evaluation of the performance criteria [16]

- Movimiento de pellizco/pinza:
Uno de los patrones de agarre más importantes es el agarre con pellizco. Este agarre es la coordinación del dedo índice y el pulgar para sostener un objeto. Durante esta operación, la falange distal permanece recta o gira en sentido antihorario, mientras que con el movimiento convencional de los dedos, todas las falanges giran en el sentido de las agujas del reloj (Fig. 3). En otras palabras, considerando la etapa recta inicial de las falanges, la falange distal solo realiza un movimiento de traslación (Fig. 4).
La prevalencia del movimiento de pellizco no es tanto como la de los movimientos naturales y de adaptación a la forma, pero parece particularmente beneficioso para agarrar objetos delgados, por tendones y por engranajes que realizan el proceso de pellizco en su funcionamiento.



> Figura 7. Comparación de la motoína convencional (a) y el movimiento de pellizco (b) del dedo humano. [16]



> Figura 8. Proceso de prensión paralela del dedo. (a) Etapa inicial (b) última etapa. [16]

- Estabilidad:
El principal deber de una mano protésica es agarrar y manipular diferentes objetos de forma estable y segura para disminuir la posibilidad de deslizamiento y falla en el agarre. 
Se han desarrollado varias estrategias para la prevención de resbalones y el control de la fuerza empleado para obtener un agarre firme. Dado que el principio en el proceso de agarre es que todos los dedos involucrados están individualmente estables, en el presente estudio, un agarre es estable si y sólo si cada dedo está en equilibrio estático. En otras palabras, según el diagrama de cuerpo libre, las fuerzas de contacto deben ser positivas o cero en un agarre estable. 

#### Características físicas

- Peso: El número de falanges, el tipo de mecanismo, la dimensión geométrica y el material utilizado en la estructura afectan directamente el peso de un dedo. A modo de ejemplo, cuanto más compacta es la estructura, menos peso pesa el dedo. 

- Número de falanges: Una prótesis de dedo de tres falanges no sólo tiene similitud con la mano humana sino que también mejora el rendimiento de agarre. Sin embargo, esta característica puede causar una mayor complejidad de la estructura y el peso de la prótesis. Dado que la simplicidad en el diseño de una mano artificial es una prioridad, la mayoría de los dedos artificiales comerciales han sido desarrollados por una o dos falanges.

- Compacidad: La compacidad de un dedo se define como la relación entre el ancho y el largo de un dedo. Para producir una prótesis de mano que cumpla con los factores estéticos, es necesario no tener características sobresalientes.

- Proceso de manufactura: Se pueden utilizar varios métodos para fabricar las piezas mecánicas de una prótesis de mano. Una técnica típica es mecanizar metales ligeros como el aluminio. El coste y el tiempo de mecanizado de una mano biónica serían elevados debido a las piezas diminutas y diseños complicados. 

| | Sugerencias y consideraciones |
| :---: | :--- |
| 1 | Definir una tarea particular para una prótesis puede resultar ventajoso. Una prótesis para tareas de la vida diaria se prefiere que sea sencilla y robusta. |
|2| Para realizar patrones de agarre de precisión, tienen preferencia los dedos con un solo grado de libertad.|
|3| En los patrones de agarre de fuerza, los mecanismos de adaptación de forma realizan un agarre más estable.|
|4| La incorporación de restricciones mecánicas apropiadas reduce la aparición del fenómeno de expulsión en los mecanismos de adaptación de forma y la posterior falla en el agarre.|
|5| Cuanto mayor sea el número de resortes ubicados en un mecanismo, mayor será el consumo de batería. Por lo tanto, el diseñador debería optar por menos muelles con baja rigidez, aunque hasta el punto de no perjudicar la funcionalidad.|
|6| El desarrollo de materiales con una alta relación resistencia-densidad, como las fibras de carbono, tiene ventajas considerables en el área de las prótesis. Las limitaciones de fabricar una mano con materiales compuestos deben considerarse en el proceso de diseño. |

>Tabla 3. [16]

----

## Estado del arte científico:

### Ensayos clínicos

| Título del ensayo clínico | Conclusiones |
| :---: | :---: |
|“Affordable 3D-printed tendon prosthetic hands: Expectations and benchmarking questioned” |  En resumen, las prótesis evaluadas obtuvieron una puntuación baja en el SHAP en comparación con manos más especializadas como la i-Limb de Ossur, lo que sugiere que no son adecuadas para manipular objetos pequeños. Las manos más funcionales incluyen InMoov, limitless y el Ada hand. Se destaca la importancia de utilizar material engomado en las áreas de contacto con objetos y considerar la geometría del pulgar. [26] |
|“3D-printed custom-designed prostheses for partial hand amputation: Mechanical challenges still exist”| Ambas prótesis 3D tienen poco agarre y fuerza de pinza, pero destreza comparable a una mioeléctrica. El participante estaba más cómodo con el peso y propiedades térmicas de los dispositivos 3D. El problema de la baja fuerza de agarre es común en evaluaciones de modelos 3D de prótesis. [27] |
|“Measuring Satisfaction With Upper Limb Prostheses: Orthotics and Prosthetics User Survey Revision That Includes Issues of Concern to Women” | Es importante evaluar la satisfacción con las prótesis de miembros superiores dado que la satisfacción es predictiva del abandono del dispositivo. Las personas con ULA que no utilizan prótesis refieren mayor dificultad con actividades, más discapacidad y mayor probabilidad de necesitar asistencia, en comparación con los usuarios de dispositivos. [28] |
|“Activity and Participation, Bimanual Function, and Prosthesis Satisfaction are Strong Predictors of General Well-Being Among Upper Limb Prosthesis Users”| Se descubrió que la duración de uso de la prótesis por parte de los pacientes no está relacionada con su bienestar. En cambio, la satisfacción con la prótesis está más relacionada con la capacidad de realizar actividades bimanuales y participar en roles y actividades sociales que con la cantidad de tiempo que la persona utiliza la prótesis durante el día. [29] |
|“Prosthetic hand control: A multidisciplinary review to identify strengths, shortcomings, and the future”| Este estudio recomendó incrementar las opciones de agarre en las prótesis para permitir a los pacientes realizar funciones esenciales en su vida diaria. También destacó la importancia de incorporar sensores táctiles que proporcionen información variada. Otra clave fue la necesidad de agregar un mecanismo para que los usuarios no necesiten mantener contacto visual constante, lo que les permitiría realizar otras tareas de manera más natural. [30] |
|“User experiences of digital prostheses in daily functioning in people with an amputation of thumb or finger”| Este estudio examinó cómo las prótesis digitales afectan la vida diaria de los usuarios. Los participantes valoraron la autonomía y la capacidad de llevar a cabo actividades por sí mismos con la ayuda de estas prótesis. También se destacó su contribución a la restauración de la imagen corporal después de una amputación. En resumen, las prótesis digitales se consideran herramientas valiosas para recuperar la vida anterior a la amputación, brindando independencia y participación en la sociedad. [31] |

### Dificultades de las prótesis de manos para realizar el movimiento de agarre de pinza

Muchas de las prótesis tienen problemas para realizar el movimiento de pinza. El énfasis en la destreza y la capacidad del pulgar y el índice tiene un costo en el desempeño de la fuerza de prensión. Sin embargo, estos dedos aún podrían contribuir a agarrar y estabilizar un objeto, especialmente si el objeto es liviano o si se necesita poca fuerza. Por tanto, la prótesis puede tener capacidades de fuerza aceptables para algunos amputados. [17]

La destreza de una mano determina los movimientos finos y los agarres precisos y se clasifica en dos categorías: poder y agarre de precisión.
El pulgar es fundamental para la estabilidad de los agarres tanto de potencia como de precisión. Se opone a la fuerza de los dedos para un agarre potente y permite agarres de precisión como el pellizco lateral. Por lo tanto, el pulgar está presente en la mayoría de las prótesis y manos de robots.

La impresión 3D podría permitir un uso eficiente del material para lograr estructuras ligeras pero duraderas. Aunque los micromotores son actuadores comunes y eficaces, los sistemas hidráulicos en miniatura también tienen potencial. Un mecanismo activo de bloqueo del pulgar, la muñeca o la articulación, con control intuitivo, podría mejorar sustancialmente la funcionalidad si no es demasiado pesado. [18]

### Más de la impresión 3D:

- Inicialmente utilizado para superar el alto coste de las prótesis de las extremidades superiores, el primer dispositivo impreso en 3D ampliamente disponible fue el Robohand. Desarrollado en 2011, cuesta aproximadamente £1600 por un dispositivo completamente ensamblado. 
- Si bien posee aspectos ventajosos como un costo dramáticamente reducido y su peso relativamente liviano, solo es adecuado para pacientes que tienen una muñeca funcional. Además, los dedos del dispositivo no pueden abrirse y cerrarse independientemente uno del otro, lo que limita la practicidad de la prótesis.
- Un beneficio importante de la impresión 3D para prótesis de extremidades superiores es que las piezas se pueden personalizar convenientemente para satisfacer los requisitos estéticos y funcionales del paciente.
- Los costos de producción antes mencionados se reducen considerablemente, un beneficio importante para los pacientes que luchan por acceder a las opciones convencionales. Sin embargo, actualmente falta la funcionalidad de estos dispositivos. En consecuencia, es necesario un mayor desarrollo en este sector. [13]

#### Mecanismos de resortes empleados en prótesis para dedos de la mano:

- En la prótesis de Atique y Rabbani (2018), los resortes realizan la acción de agarre principal del pulgar; sin embargo, el motor es el que opera bajo el control de la señal EMG para poder abrir el pulgar. Esta señal es producida voluntariamente por el usuario a través de la contracción muscular. El motor ayudará a abrir y sostener la posición abierta aplicando torque contra el resorte. Para cerrar el pulgar, el motor para de ejercer fuerza contra el mecanismo de resorte y este cierra el pulgar, el cual será iniciado otra vez por otra señal EMG.



> Figura 9. [19]

- En el caso de la prótesis de Laliberte y Gosselin, el dedo es accionado a través del eslabón inferior, como se muestra en a). Asimismo, se debe utilizar un resorte de extensión que mantendrá el dedo completamente extendido y un límite mecánico para mantener las falanges alineadas bajo la acción del resorte cuando no se apliquen fuerzas externas a las falanges. En a), el dedo no presenta fuerzas externas, por lo que se comporta como un solo cuerpo rígido en rotación alrededor de un pivote fijo. En b), la falange proximal entra en contacto con el objeto. En c), la segunda falange se mueve con respecto a la primera y el dedo se cierra sobre el objeto, ya que la falange proximal está restringida por el objeto. Durante esta fase, el actuador debe producir la fuerza necesaria para extender el resorte. Finalmente, en d), ambas falanges están en contacto con el objeto y el dedo ha completado la fase de adaptación de forma. Las fuerzas aplicadas en el actuador se distribuyen entre las falanges.



> Figura 10. [20]

-La propuesta de Yon y Choi (2017), consta de tres falanges utilizando uniones apilables de cuatro barras. Cada falange tiene su propia articulación conectada a un resorte lineal para la falange principal. Las falanges se apilan en paralelo y comparten algunas articulaciones comunes. El mecanismo está accionado por un solo actuador lineal y la posición del dedo puede ser reconfigurada a medida que los resortes lineales de los eslabones se deforman. Los eslabones de la articulación fijada giran en sentido horario a medida que la articulación se contrae desde su posición original. Cuando la articulación de la falange distal o de la media está en contacto con un objeto, el eslabón se queda fijo, pero aún la articulación puede desplazarse a lo largo de la línea discontinua. Básicamente, los eslabones pueden seguir girando porque el resorte lineal del eslabón está contraído, como se ilustra en la Figura .



> Figura 11. [21]

- Yang y Zhao (2009) diseñaron la estructura principal del dedo índice como un mecanismo de dos barras articuladas que se unen en la articulación interfalángica proximal (PIP). Además, utilizaron un resorte de torsión pretenso para mantener la falange media en su posición predeterminada con respecto a la falange proximal y para encargarse de la función de subaccionamiento. Básicamente, el dedo permanece recto mientras gira alrededor de la articulación metacarpofalángica (MCP) hasta que la falange proximal se detenga debido a una fuerza resistente adecuada (Figura 2a); asimismo, mientras la falange media gira alrededor de la articulación PIP (Figura 2b), la falange distal gira alrededor de la articulación interfalángica distal (DIP) al mismo tiempo, ya que son dos barras constituyentes del segundo mecanismo de cuatro barras. En el caso del pulgar, se puede describir como un mecanismo con tres falanges y tres articulaciones, cuyo metacarpiano está inclinado 60 grados (no vertical) con respecto al eje de la articulación TM para que el pulgar se mueva a lo largo de una superficie cónica.



> Figura 12 [22]
- En la prótesis realizada por Chen (2017) constaba de un mecanismo en el cual el resorte de torsión 2 se conecta al engranaje 1 y al eje del motor para ambos dedos, cuya rigidez es mayor que la del resorte de torsión 1 incorporado en el dedo, como se muestra en la Figura 3(b). Cuando comienza la sujeción, el motor fijo en la palma hace girar el eje del motor. Como se muestra en la Figura 3(a), antes de que los dos dedos toquen el objeto, se asume que el eje del motor está fijo con el engranaje 2 debido al resorte 2 conectado, y hace que los dedos funcionen en modo de sujeción acoplada. Cuando la falange proximal del dedo trasero colisiona con el objeto, el resorte 1 del dedo trasero comienza a doblarse primero y entra en su sujeción autoadaptativa. Después, el resorte 2 que conecta el dedo trasero y el eje del motor comienza a doblarse; por lo tanto, aunque el dedo trasero está bloqueado por el objeto, el motor todavía puede girar hasta que el dedo delantero logre su sujeción autoadaptativa. Además, esto protege al motor de daños cuando se produce un impacto repentino en los dedos.



}

> Figura 13. [13]

- Lotti (2005) diseñó un mecanismo en el cual las articulaciones presentan resortes con un número definido de espirales necesarios para obtener los desplazamientos deseados y evitar el pandeo, es decir, desplazamientos transversales a la dirección principal de compresión. Estos resortes pueden ser ubicados en paralelo con el fin de obtener un mecanismo de bisagra y proponen una alternativa de manejar una articulación por tendón, entonces la rigidez del dedo dependerá de la rigidez del resorte y la retracción se logrará por la elasticidad de la flexión, pero esto no puede ser controlado, de otro modo se pueden asociar dos tendones antagonistas a la articulación capaz de colaborar con la bisagra en el retroceso.



> Figura 14. [14]

### Elastómeros:

- “Design and Analysis of Flexible Joints for a Robust 3D Printed Prosthetic Hand”



> Figura 15. [25]

En este estudio, se investigó una solución para mejorar la durabilidad y resistencia de las prótesis de mano impresas en 3D. Se analizaron las articulaciones flexibles de estas prótesis mediante el uso de un enfoque de elementos finitos, una práctica común en la industria. Se llegó a la conclusión de que el Diseño I con un material de poliuretano demostró un buen rendimiento al imitar la posición natural de una mano humana. Este hallazgo tiene importantes implicaciones para el desarrollo de prótesis de mano impresas en 3D más robustas, que podrían beneficiar a amputados que las necesitan de manera inmediata, proporcionando una solución duradera mientras se esperan alternativas más avanzadas.



> Figura 16. [25]

### ¿Cuál es la problemática?

Pregunta reto: ¿Cómo podríamos mejorar el movimiento de pinza en una prótesis 3D del dedo pulgar?

## 📚 Bibliografía
 
[1] Billig JI, Nasser JS, Cho HE, Chou C-H, Chung KC. Association of interfacility transfer and patient and hospital characteristics with thumb replantation after traumatic amputation. JAMA Netw Open [Internet]. 2021 [citado el 10 de septiembre de 2023];4(2):e2036297. Disponible en: http://dx.doi.org/10.1001/jamanetworkopen.2020.36297 

[2] Forte AJ, Maita KC, Torres-Guzman RA, Avila FR, Safa B, Buncke G, et al. Great toe transplantation. Semin Plast Surg [Internet]. 2022 [citado el 10 de septiembre de 2023];36(04):243–52. Disponible en: https://pubmed.ncbi.nlm.nih.gov/36561428/ 

[3]  Matsumoto MK, Fernandes M, Moraes VY de, Raduan Neto J, Okamura A, Belloti JC. Treatment of fingertip injuries by specialists in Hand Surgery in Brazil. Acta Ortop Bras [Internet]. 2018 [citado el 10 de septiembre de 2023];26(5):294–9. Disponible en: http://dx.doi.org/10.1590/1413-785220182604187738 

[4]  Instituto Nacional de Rehabilitación. Norma Técnica de Salud para la Evaluación, Calificación y Certificación de la Persona con Discapacidad [Internet]. Gob.pe. [citado el 10 de septiembre de 2023] Disponible en: http://bvs.minsa.gob.pe/local/MINSA/5741.pdf 

[5] Observatorio Nacional de la Discapacidad [Internet]. Gob.pe. [citado el 10 de septiembre de 2023]. Disponible en: https://conadisperu.gob.pe/observatorio/estadisticas/graficos-estadisticos/ 

[6] Skirven TM, Lee Osterman A, Fedorczyk J, Amadio PC, Felder S, Shin EK. Rehabilitation of the Hand and Upper Extremity. Elsevier Health Sciences; 2020.

[7] Ruiz-Riquelme P, Urrutia-Hoppe E. Cobertura de partes blandas del Pulgar. Guía en la toma de decisiones. Rev Colomb Ortop Traumatol [Internet]. 2021 [citado el 6 de septiembre de 2023];35(1):67–73. Disponible en: https://www.elsevier.es/es-revista-revista-colombiana-ortopedia-traumatologia-380-articulo-cobertura-partes-blandas-del-pulgar--S0120884521000110 

[8] Saudabayev A, Rysbek Z, Khassenova R, Varol HA. Human grasping database for activities of daily living with depth, color and kinematic data streams. Sci Data [Internet]. 2018 [citado el 14 de septiembre de 2023];5(1):1–13. Disponible en: https://www.nature.com/articles/sdata2018101 

[9] Smith J, Petrovic P, Rose M, De Souz C, Muller L, Nowak B, et al. Placeholder Text: A Study. Citation Styles. 15 de julio de 2021;3. Disponible en:
https://ieeexplore-ieee-org.ezproxybib.puce/document/9896512 

[10] Jing X, Yong X, Li G, Jiang J, Yokoi H. Design of A Prosthetic Hand for Multiple hand Motions. En: 2019 IEEE International Conference on Robotics and Biomimetics (ROBIO). IEEE; 2019. p. 2814–9. Disponible en:
https://ieeexplore-ieee-org.ezproxybib.pucp.edu.pe/document/8961418 
[11]Kanitz G, Cipriani C, Edin BB. Classification of Transient Myoelectric Signals for the Control of Multi-Grasp Hand Prostheses. IEEE Transactions on Neural Systems and Rehabilitation Engineering. Septiembre de 2018;26(9):1756–64. Disponible en:
https://ieeexplore-ieee-org.ezproxybib.pucp.edup.edu.p.pe/document/8423679 

[12] Gracia-Ibáñez V, Sancho-Bru JL, Vergara M. Relevance of grasp types to assess functionality for personal autonomy. Journal of Hand Therapy. Enero de 2018;31(1):102–10.  
https://pubmed.ncbi.nlm.nih.gov/28341325/ 

[13] Brack R, Amalu EH. A review of technology, materials and R&D challenges of upper limb prosthesis for improved user suitability. J Orthop [Internet]. 2021;23:88–96. Disponible en: https://www.sciencedirect.com/science/article/pii/S0972978X20303615

[14] Smail LC, Neal C, Wilkins C, Packham TL. Comfort and function remain key factors in upper limb prosthetic abandonment: findings of a scoping review. Disabil Rehabil Assist Technol [Internet]. 2021;16(8):821–30. Disponible en: http://dx.doi.org/10.1080/17483107.2020.1738567

[15] Difonzo E, Zappatore G, Mantriota G, Reina G. Advances in finger and partial hand prosthetic mechanisms. Robotics [Internet]. 2020 [citado el 13 de septiembre de 2023];9(4):80. Disponible en: https://www.mdpi.com/2218-6581/9/4/80

[16] Kashef SR, Amini S, Akbarzadeh A. Robotic hand: A review on linkage-driven finger mechanisms of prosthetic hands and evaluation of the performance criteria. Mech Mach Theory [Internet]. 2020;145(103677):103677. Disponible en: https://www.sciencedirect.com/science/article/pii/S0094114X19322839

[17] Damerla R, Qiu Y, Sun TM, Awtar S. A review of the performance of extrinsically powered prosthetic hands. IEEE Trans Med Robot Bionics [Internet]. 2021;3(3):640–60. Disponible en: https://ieeexplore.ieee.org/abstract/document/9499232

[18] Vertongen J, Kamper DG, Smit G, Vallery H. Mechanical aspects of robot hands, active hand orthoses, and prostheses: A comparative review. IEEE ASME Trans Mechatron [Internet]. 2021;26(2):955–65. Disponible en: https://ieeexplore.ieee.org/abstract/document/9157986

[19]	Atique MDM, Rabbani S-E. A cost-effective myoelectric prosthetic hand. J Prosthet Orthot [Internet]. 2018 [citado el 16 de octubre de 2023];30(4):231–5. Disponible en: https://journals.lww.com/jpojournal/Fulltext/2018/10000/A_Cost_Effective_Myoelectric_Prosthetic_Hand.10.aspx

[20]	Laliberte T, Gosselin CM. Underactuation in space robotic hands [Internet]. Esa.int. [citado el 16 de octubre de 2023]. Disponible en: http://robotics.estec.esa.int/i-SAIRAS/isairas2001/papers/Paper_AM025.pdf

[21]	Yoon D, Choi Y. Underactuated finger mechanism using contractible slider-cranks and stackable four-bar linkages. IEEE ASME Trans Mechatron [Internet]. 2017 [citado el 16 de octubre de 2023];22(5):2046–57. Disponible en: https://www.semanticscholar.org/paper/c794d81938b661cde8fdc24c9bcbe28fcba7dd89 

[22]	Yang D-P, Zhao J-D, Gu Y-K, Wang X-Q, Li N, Jiang L, et al. An anthropomorphic robot hand developed based on underactuated mechanism and controlled by EMG signals. J Bionic Eng [Internet]. 2009;6(3):255–63. Disponible en: https://www.sciencedirect.com/science/article/pii/S1672652908601195 

[23] 	Li X, Huang Q, Chen X, Yu Z, Zhu J, Han J. A novel under-actuated bionic hand and its grasping stability analysis. Adv Mech Eng [Internet]. 2017;9(2):168781401668885. Disponible en: http://dx.doi.org/10.1177/1687814016688859 

[24]	Lotti F, Tiezzi P, Vassura G, Biagiotti L, Palli G, Melchiorri C. Development of UB hand 3: Early results [Internet]. Psu.edu. [citado el 16 de octubre de 2023]. Disponible en: https://citeseerx.ist.psu.edu/document?repid=rep1&type=pdf&doi=0117484957f64b4891a65341908997202d835872 

[25]  Alkhatib F, Mahdi E, Cabibihan J-J. Design and analysis of flexible joints for a robust 3D printed prosthetic hand. En: 2019 IEEE 16th International Conference on Rehabilitation Robotics (ICORR). IEEE; 2019.

[26]  Andrés-Esperanza J, Iserte-Vilar JL, Llop-Harillo I, Pérez-González A. Affordable 3D-printed tendon prosthetic hands: Expectations and benchmarking questioned. Eng Sci Technol Int J [Internet]. 2022;31(101053):101053. Disponible en: https://www.sciencedirect.com/science/article/pii/S2215098621001749 

[27]  Andrés-Esperanza J, Iserte-Vilar JL, Llop-Harillo I, Pérez-González A. Affordable 3D-printed tendon prosthetic hands: Expectations and benchmarking questioned. Eng Sci Technol Int J [Internet]. 2022;31(101053):101053. Disponible en: https://www.sciencedirect.com/science/article/pii/S2215098621001749 

[28]  Resnik LJ, Borgia ML, Clark MA, Heinemann AW, Ni P. Measuring satisfaction with upper limb prostheses: Orthotics and prosthetics user survey revision that includes issues of concern to women. Arch Phys Med Rehabil [Internet]. 2022;103(12):2316–24. Disponible en: https://www.sciencedirect.com/science/article/pii/S000399932200418X

[29]  Stevens PM, England DL, Todd AE, Mandacina SA, Wurdeman SR. Activity and participation, bimanual function, and prosthesis satisfaction are strong predictors of general well-being among upper limb prosthesis users. Arch Rehabil Res Clin Transl [Internet]. 2023;5(2):100264. Disponible en: https://www.sciencedirect.com/science/article/pii/S2590109523000162

[30]  Kumar DK, Jelfs B, Sui X, Arjunan SP. Prosthetic hand control: A multidisciplinary review to identify strengths, shortcomings, and the future. Biomed Signal Process Control [Internet]. 2019;53(101588):101588. Disponible en: https://www.sciencedirect.com/science/article/pii/S1746809419301685

[31]  Van Heijningen VG, Underhill A. User experiences of digital prostheses in daily functioning in people with an amputation of thumb or finger. J Hand Ther [Internet]. 2022;35(2):289–98. Disponible en: https://www.sciencedirect.com/science/article/pii/S0894113022000035

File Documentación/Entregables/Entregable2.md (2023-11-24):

# Segundo entregable

## Estado del arte comercial

### Patentes

#### US2022346985A1







##### Información:

Inventores: Pulver, Ben; Kishek, Serena; Sliker, Levin; Huddle, Stephen; Vertedero, Richard; Segil, Jacob

| | Fecha |
| :--: | :---: |
| **Publicado** | 9-02-2022 |
| **Publicación** | 3-11-2022 |

##### Descripción:

Se refiere a un dispositivo protésico diseñado para ayudar a los usuarios que han perdido un dedo, como el pulgar, a restaurar las funciones de la mano. Este dispositivo permite al usuario mover su dedo protésico en movimientos de aducción y abducción, lo que significa que pueden posicionar el dedo protésico en diferentes orientaciones en relación con los otros dedos de la mano. Esto es importante para adaptar la prótesis a diversas tareas, como agarrar objetos o mantener una posición de descanso.

El dispositivo se puede acoplar a un encaje protésico personalizado que se ajusta a la parte restante de la mano del usuario. Consiste en un carril que se extiende sobre la región del pulgar del usuario y parte de la palma de la mano. Un carro se mueve a lo largo del carril y sujeta de manera móvil un dedo protésico, como una prótesis de pulgar, permitiendo así un rango de movimiento similar al de un pulgar natural. El usuario puede utilizar el dispositivo para posicionar el dedo protésico en diferentes orientaciones y llevarlo a una posición de oposición con otros dedos de la mano, permitiéndoles realizar diversas acciones.

##### Mecanismo:

Su función principal es permitir al usuario fijar el dedo protésico (por ejemplo, una prótesis de pulgar) en una posición deseada y segura para llevar a cabo tareas específicas, como agarrar objetos.

Este mecanismo de bloqueo puede operar de diferentes maneras:

- Activación manual: El usuario puede activar y desactivar manualmente el mecanismo de bloqueo según sea necesario. Cuando activa el mecanismo, el dedo protésico se bloquea en su posición actual. Cuando lo desactiva, puede mover el dedo protésico a una nueva posición.
- Activación automática: En algunos casos, el mecanismo de bloqueo se activa automáticamente, y el usuario puede habilitar una función de liberación para mover el dedo protésico. Esto significa que el mecanismo está en un estado bloqueado por defecto y solo se desbloquea cuando el usuario lo necesita. Cuando se desactiva la función de liberación, el mecanismo vuelve a bloquear el dedo protésico en su lugar.
  
**Diferentes estados de bloqueo:** El mecanismo de bloqueo puede tener varios estados, como un estado de movimiento libre, un estado semilibre y un estado bloqueado. Cada uno de estos estados proporciona un nivel diferente de bloqueo y movilidad para el dedo protésico. Por ejemplo, en el estado de movimiento libre, el carro puede moverse en cualquier dirección, mientras que en el estado bloqueado, no se permite ningún movimiento sin la intervención del usuario.

**Orientación similar de la fuerza:** En algunos casos, el mecanismo de bloqueo está diseñado de manera que la dirección en la que se debe aplicar la fuerza para desbloquearlo sea similar o sustancialmente la misma que la dirección en la que el carro se mueve a lo largo de la pista. Esto facilita que el usuario desbloquee y mueva el dedo protésico utilizando partes de su cuerpo o elementos cercanos, lo que mantiene su otra mano libre para realizar otras tareas.

El mecanismo de bloqueo es fundamental para permitir la flexibilidad y la adaptabilidad del dispositivo protésico, lo que permite al usuario posicionar el dedo protésico de manera segura para diferentes actividades y luego cambiar la posición según sea necesario. Esto hace que la prótesis sea más funcional y versátil en la vida cotidiana del usuario.

---- 

#### CN115844602A 





##### Información: 

Inventores: Chen Wenbin; Jang Yoon-Chul; Yan Yu; Cai Junjie; Xiong Caihua

| | Fecha |
| :--: | :---: |
| **Publicado** | 09-12-2022 |
| **Publicación** | 28-03-2023 |

##### Descripción:

Presenta un pulgar blando articulado humanoide con múltiples cámaras de aire que ofrece varios beneficios significativos:

- Control Integral: El pulgar blando permite controlar la flexión y extensión del pulgar a través de la rama principal y el balanceo lateral a través de las dos ramas auxiliares. Esto da como resultado una apariencia y un funcionamiento humanoides tanto en estado de reposo como durante el proceso de agarre. Esta relación antropomórfica entre apariencia y función mejora la experiencia del usuario.
- Mayor Fuerza de Salida y Eficiencia: El diseño con ramas auxiliares que solo existen en la parte inferior del pulgar permite una mayor flexibilidad y fuerza de salida. En comparación con los actuadores suaves tradicionales de tres cámaras con cámaras de aire dispuestas en arcos iguales, este pulgar blando es más eficiente y ofrece una mayor fuerza de salida.
- Coordinación Anatómica: El pulgar blando se coordina anatómicamente con las articulaciones de la mano humana. Las articulaciones correspondientes a la cámara que impulsa el movimiento del pulgar tienen funciones equivalentes a las tres articulaciones del pulgar de la mano humana. Esto permite un funcionamiento más natural y antropomórfico.
- Diseño Eficaz de Hilos de Fibra: Los hilos de fibra enrollados en doble hélice en el tubo superior y las ramas auxiliares aseguran una limitación de la expansión radial cuando se infla el interior del pulgar. Esto resulta en una flexión y oscilación lateral controladas, contribuyendo a la suavidad y precisión de los movimientos del pulgar blando.

##### Mecanismo:

El pulgar blando se controla mediante la inflación y deflación de las cámaras de aire, lo que permite flexionar y extender el pulgar, así como lograr movimientos de oscilación lateral. El diseño antropomórfico del pulgar blando encaja con la apariencia y la función de un pulgar humano. Esto mejora la experiencia del usuario y su aceptación, especialmente para personas con discapacidades en las mano.

La estructura del pulgar blando consta de una cubierta blanda, un tubo de silicona, un tubo corrugado y una interfaz. El tubo de silicona incluye un tubo de silicona interno con un tubo superior y un tubo inferior, ambos conectados en secuencia. El tubo superior tiene forma cuadrada con un lado en forma de arco, que se asemeja a la superficie exterior del pulgar. El tubo inferior se divide en una rama principal y dos ramas auxiliares, todas con hilos de fibra enrollados simétricamente en doble hélice. La cubierta blanda rodea el tubo superior, y el fuelle rodea el tubo inferior. El tubo corrugado conecta la parte superior de la carcasa blanda con la parte inferior del fuelle, y la interfaz tiene tres aberturas conectadas a la rama principal y las dos ramas auxiliares del tubo inferior.

----

#### CN107280825A



##### Información:
Inventores:

| | Fecha |
| :--: | :---: |
| **Publicado** | 24-10-2017 |
| **Publicación** | 15-01-2019 |

##### Descripción:

Esta patente abarca principalmente la problemática presente en artefactos de manufactura digital, los cuales presentan deficiencias dentro de la función de pinza, siendo más específicos, la carencia de precisión del agarre en figuras geométricas representadas en objetos de consumo humano, los cuales provocan dificultades en los pacientes con estas discapacidades.

##### Mecanismo: 

El mecanismo propuesto consiste en que la parte conexión de la palma y pulgar están conectados mediante una sección plana, un tornillo está conectado con la tuerca incrustada en la conexión del pulgar a través de una arandela y el resorte de compresión incrustado en la conexión de palma, de tal manera que la conexión del pulgar y la palma estén conectados elásticamente mediante un resorte helicoidal grande. Dentro de esa zona, están provistas de dientes frontales, con engranajes y conectadas con los dientes del otro extremo, lo cual ocasiona que la parte de conexión de la palma se adapta mientras se conecta a una sujeción circunferencial en el lado medial de la palma a través del pandeo. Los pernos y resortes de compresión están conectados de manera pivoteada a la palma, proporcionando una conexión elástica a la palma.

El ángulo de rotación del dedo pulgar conectado alrededor del eje central entre la porción de conexión de la palma y el pulgar se puede modificar mediante el ajuste de localización del acoplamiento de los dientes faciales entre aquellas secciones.
La porción de conexión de la palma de la mano y la palma mediante ajustes alrededor del centro de conexión de la palma,  cambiando la posición de acoplamiento entre la hebilla circunferencial de la porción de la palma y el surco de captura circunferencial de la palma, pueden modificar el ángulo de rotación del pulgar.

Este mecanismo de dedo pulgar presenta aspectos favorables las cuales son las siguientes:

- Sistema de ajuste angular óptimo: Configurado manualmente mediante el ajuste de las posiciones de conexión de los dientes extremos de la porción de la palma, las ranuras de bloqueo circunferenciales en la porción de la palma y la porción conectada en el pulgar, priorizando la sujeción ligera del pulgar en todo momento 
- Fijación del pulgar: Disponible en cualquier posición dentro del rango establecido, otorgando mayor libertad dentro de la función de agarre y la posibilidad de expandir funciones más específicas. 

----

### Productos comerciales

#### Mano bebionic EQD



>Figura 5. [5]

- Audiencia: Dirigido desde adolescentes hasta adultos de la tercera edad con nivel de actividad de baja a moderada.

- Partes del producto:

1. Falange distal
2. Falange media 
3. Cadena de tracción del dedo 
4. Conmutador de programa
5. Dorso de la mano
6. Muñeca
7. Articulación carpometacarpiana del pulgar
8. Funda 
9. Falange distal del pulgar

- Descripción: 
Prótesis mioeléctrica con múltiples articulaciones y tres variantes de muñeca. Posee dedos de movimiento pasivo, los cuales al chocar con objetos de manera involuntaria se doblan para proteger el sistema mecánico. Pulgar ajustable a posición lateral y oposición. Posee 14 modos de agarre, los cuales incluye: Agarre de pinza, agarre de tres dedos, agarre de apriete, agarre de gancho, agarre en punta, agarre de precisión cerrado, agarre de precisión abierto, agarre de interruptor, extensión dedo índice, agarre de llaves, agarre de ratón, mano de plato y posición neutra. 

- Especificaciones técnicas: 

Vida útil de 5 años. 

Bluetooth Smart/Low Energy con un alcance mínimo de 2 m

Apertura del dedo índice de 0.75 mm.

Peso de 402 g.

- Patentes de la prótesis:

Canadá: CA 2 767 121

Estados Unidos: US 9 101 499; US 9 592 134

Europa: EP 2510906 en Austria, Suiza, Alemania, Francia, Reino Unido, Italia y Suecia.
  
- Otras certificaciones: 

Cumple con la exigencia de las normativas europeas CE y  la directiva 2014/53/UE.

El producto se ajusta a las normas IEC 60601-1:2005/A1:2012.

Cumple con los requisitos del “FCC part 15” de Estados Unidos.

Cumple con los requisitos del “Radiocommunication Act” de Australia.

------

#### Limb Quantum


  
>Figura 6 [6]

- Audiencia: Enfocado a un rango de edad entre adolescentes hasta personas de tercera edad con niveles de actividad moderado.

- Descripción: Es una prótesis de miembro superior mioeléctrica elaborada de titanio los cuales benefician el agarre y velocidad en un 30%, y la carga en un 50%. Posee la capacidad de manipular cada dedo independientemente y una función de rotación equipada en el pulgar. Consta de una  selección de 36 agarres, con modificaciones estándares y personalizadas según la necesidad del consumidor. Además, posee funciones como el Vari-Grip el cual permite incrementar la aplicación de fuerza de agarre, también otorga garantía anticaídas con la función Auto-grasp y aplicaciones virtuales de configuración y modificación de los agarres del producto como el Bio-sim.

- Especificaciones técnicas:

Máxima carga posible de la mano: 40 kg (extra pequeño), 90kg (pequeño-mediano-grande)

Máxima carga posible del dedo: 20kg (extra pequeño), 48kg (pequeño-mediano-grande)

Batería: Polímero de litio, Valor nominal de 7,4V, capacidad de 2000 y 1300 mAh.

Corriente máxima equivalente a 5A.

Periodo de apertura a cierre aproximadamente de 0.8 segundos.

------

#### ThumbDriver 

- Partes del producto:



>Figura 7. [7]

1. Placa de anclaje
2. Aducción/Arandela de aducción 
3. Anclaje del pulgar 
4. Eslabones metálicos a medida
5. Tornillo de ajuste de anillo
6. Punta del dispositivo
7. Interfaz dorsal de silicona
8. Articulación de bisagra
9. Almohadilla Metacarpiana
10. Anillo de suspensión
11. Agujero de la arandela
12. Tornillo de ajuste del ángulo de la punta
13. Punta de silicona

- Descripción: Prótesis corporal diseñada para el pulgar y parte de la mano en la falange proximal del pulgar que, principalmente, permite al usuario recuperar la oposición dinámica de los dedos mientras soporta las grandes fuerzas generadas a través de la oposición. Asimismo, imita el movimiento multiaxial del pulgar, permitiendo al usuario recuperar el agarre natural, proporciona flexibilidad para diferentes patrones de oposición y presenta una opción de preflexión ajustable para que el usuario pueda adaptarlo a sus necesidades, facilitando la realización de pellizco y agarre. Además, la punta del dispositivo de la prótesis, está hecha de goma conductora para que el usuario pueda utilizar pantallas táctiles.

- Especificaciones técnicas:

Resistencia a la tracción del anillo:  80 lb <> 36 kg.

Resistente al calor: < 175°C (347°F)

Hecho con nylon 12 (medical grade)

Impermeable

| |Utilidad para la propuesta de solución  |
| --- | --- |
| ¿Qué parte del pulgar reemplaza? | Reemplaza la falange distal, media y parte de la proximal, pues ayuda a realizar movimientos multiaxiales.  |
| ¿Qué podremos rescatar de este producto? |  Está hecho de silicona en la huella y uniones con tornillos de titanio para que sea una prótesis ligera y facilite el movimiento. |

## Requerimientos

- **Requerimientos funcionales: ¿Qué es lo que el diseño debe hacer?**



- **Requerimientos no funcionales: ¿Cuáles son las propiedades del diseño?**



## 💡 Propuesta de solución:

“Prótesis 3D de dedo pulgar con micromotores y componentes para utilizar señales mioeléctricas de músculos cercanos y realizar un agarre de pinza más preciso.”

## 📚 Bibliografía
 
[1] Jiali C, Yufeng Z, Chengming C. Wrist driving wire rope transmission prosthetic hand [Internet]. Patent. CN209269994U, 2019 [citado el 14 de septiembre de 2023]. Disponible en: https://worldwide.espacenet.com/patent/search/family/067597558/publication/CN209269994U?q=pn%3DCN209269994U

[2] Didrick D. Digit Prosthesis Assembly. US Patent. 2023093422A1, 2023. Disponible en: https://worldwide.espacenet.com/patent/search/family/085572794/publication/US2023093422A1?q=US2023093422A1 

[3] Thompson R Jr, Bengtsson J, Macduff CC, Peto AC, Minnis ST, Klumper ED, et al. Bio-mechanical prosthetic thumb. US Patent. US10016289, 2018. Disponible en: https://patents.google.com/patent/US10016289B2/en

[4] Ramirez J. 3D-PRINTED MYOELECTRIC HAND PROSTHESIS WITH IMPROVED THUMB MOVEMENT. World Patent. WO2017208100, 2017. Disponible en: 
https://patentscope.wipo.int/search/en/detail.jsf?docId=WO2017208100&_cid=P20-LMJCG7-19306-1

[5] Mano bebionic EQD [Internet]. Ottobock.com. [citado el 14 de septiembre de 2023]. Disponible en: https://www.ottobock.com/es-es/product/8E71

[6] Mano biónica i-Limb® Quantum | Össur [Internet]. www.ossur.com. [cited 2023 Sep 15]. Disponible en: https://www.ossur.com/es-es/protesica/miembro-superior/i-limb-quantum#downloadsContentAnchor

[7] ThumbDriver [Internet]. Naked Prosthetics. 2019 [citado el 14 de septiembre de 2023]. Disponible en: https://www.npdevices.com/product/thumbdriver/

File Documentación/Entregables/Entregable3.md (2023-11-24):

# Tercer entregable

## 📦 Caja negra

<image align="center;" style="borde-radius: 300%;" width="600px;" src="https://github.com/Adriana-28/Repositorio_grupo_13/blob/main/Im%C3%A1genes/Captura%20de%20pantalla%202023-09-21%20232807.png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">

## Esquema de funciones

<image align="center;" style="borde-radius: 50%;" width="600px;" src="https://github.com/Adriana-28/Repositorio_grupo_13/blob/main/Im%C3%A1genes/Esquema%20de%20funciones.png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">

- **Regulador de Energía**: Regula la energía para poder distribuirla a los componentes.
- **Detectar (sensor mioeléctrico)**: Detecta las señales mioeléctricas producidas por los músculos.
- **Procesar**: Procesa la energía detectada por el sensor mioelectrico 
- **Amplifica**: Amplifica las señales mioelectricas para captar una mejor señal 
- **Filtrar:** Filtrar las señales mioelectricas necesarias 
- **Accionar micromotores:** Permiten el movimiento de cada pieza

## Matriz morfológica

<image align="center;" style="borde-radius: 50%;" width="600px;" src="https://github.com/Adriana-28/Repositorio_grupo_13/blob/main/Im%C3%A1genes/Captura%20de%20pantalla%202023-10-20%20021602.png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">

## Tabla de valoración

<image align="center;" style="borde-radius: 50%;" width="600px;" src="https://github.com/Adriana-28/Repositorio_grupo_13/blob/main/Im%C3%A1genes/2.png?raw=true">

## Conclusiones 

La propuesta número 1 resultó ser la ganadora debido a su gran facilidad de ensamblaje y uso respecto a las otras propuestas preliminares, ya que se utilizan algunos componentes más simples de utilizar; asimismo, el tipo de material seleccionado tiene una propiedad flexible dándole puntos a favor al prototipado.

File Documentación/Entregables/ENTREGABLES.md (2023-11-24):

# 💡 Acerca de nuestro proyecto

<p align="center">
  
</p>
 
  <h3 align="center">
👋 Bienvenidos al repositorio del grupo 13
  </h4>
  <h4 align="center">
     Proyecto: "Prótesis de manufactura digital del dedo pulgar"
  </h4>
</p>

## ❗ Hitos

[**- Primer hito**](https://github.com/Adriana-28/Repositorio_grupo_13/blob/main/Documentaci%C3%B3n/Entregables/Hito1.md)

[**- Segundo hito**](https://github.com/Adriana-28/Repositorio_grupo_13/blob/main/Documentaci%C3%B3n/Entregables/Hito2.md)

## 📍 Entregables
[**- Primer entregable ✅**](https://github.com/Adriana-28/Repositorio_grupo_13/blob/main/Documentaci%C3%B3n/Entregables/Entregable1.md)<br>  
[**- Segundo entregable ✅**](https://github.com/Adriana-28/Repositorio_grupo_13/blob/main/Documentaci%C3%B3n/Entregables/Entregable2.md)<br>

[**- Tercer entregable ✅**](https://github.com/Adriana-28/Repositorio_grupo_13/blob/main/Documentaci%C3%B3n/Entregables/Entregable3.md)<br>

[**- Cuarto entregable ✅**](https://github.com/Adriana-28/Repositorio_grupo_13/blob/main/Documentaci%C3%B3n/Entregables/Entregable4.md)<br>

[**- Quinto entregable ✅**](https://github.com/Adriana-28/Repositorio_grupo_13/blob/main/Documentaci%C3%B3n/Entregables/Entregable5.md)<br>

[**- Sexto entregable ✅**](https://github.com/Adriana-28/Repositorio_grupo_13/blob/main/Documentaci%C3%B3n/Entregables/Entregable6.md)

[**- Séptimo entregable ✅**](https://github.com/Adriana-28/Repositorio_grupo_13/blob/main/Documentaci%C3%B3n/Entregables/Entregable%207.md)

[**- Octavo entregable ✅**](https://github.com/Adriana-28/Repositorio_grupo_13/blob/main/Documentaci%C3%B3n/Entregables/Entregable%208.md)

## 📄 Actas

[**- Primera acta**](https://github.com/Adriana-28/Repositorio_grupo_13/blob/main/Documentaci%C3%B3n/Actas/Acta1.pdf)<br>

[**- Segunda acta**](https://github.com/Adriana-28/Repositorio_grupo_13/blob/main/Documentaci%C3%B3n/Actas/Acta2.pdf)<br>

[**- Tercera acta**](https://github.com/Adriana-28/Repositorio_grupo_13/blob/main/Documentaci%C3%B3n/Actas/Acta3.PDF)

[**- Cuarta acta**](https://github.com/Adriana-28/Repositorio_grupo_13/blob/main/Documentaci%C3%B3n/Actas/Acta%204.pdf)

[**- Quinta acta**](https://github.com/Adriana-28/Repositorio_grupo_13/blob/main/Documentaci%C3%B3n/Actas/Acta%205.pdf)

[**- Sexta acta**](https://github.com/Adriana-28/Repositorio_grupo_13/blob/main/Documentaci%C3%B3n/Actas/Acta%206.pdf)

[**- Séptima acta**](https://github.com/Adriana-28/Repositorio_grupo_13/blob/main/Documentaci%C3%B3n/Actas/Acta%207.pdf)

[**- Octava acta**](https://github.com/Adriana-28/Repositorio_grupo_13/blob/main/Documentaci%C3%B3n/Actas/Acta%208.pdf)

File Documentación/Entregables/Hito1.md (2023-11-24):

# Hito 1

## Solución - Propuesta

“Prótesis 3D de dedo pulgar con micromotores y componentes para utilizar señales mioeléctricas de músculos cercanos y realizar un agarre de pinza más preciso.”

## Boceto seleccionado



## Modelo 3D del ensamble




## Link de la presentación

[**PPT de la presentanción del Hito 1**](https://www.canva.com/design/DAFyRxqC7wM/DBp0C49TtiZOSL1GazJYxA/edit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)

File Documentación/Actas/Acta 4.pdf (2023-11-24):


4

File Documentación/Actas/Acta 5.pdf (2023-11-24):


4

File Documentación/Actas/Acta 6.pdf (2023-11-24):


4

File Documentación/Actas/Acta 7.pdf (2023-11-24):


4

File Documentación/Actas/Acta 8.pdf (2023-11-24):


4



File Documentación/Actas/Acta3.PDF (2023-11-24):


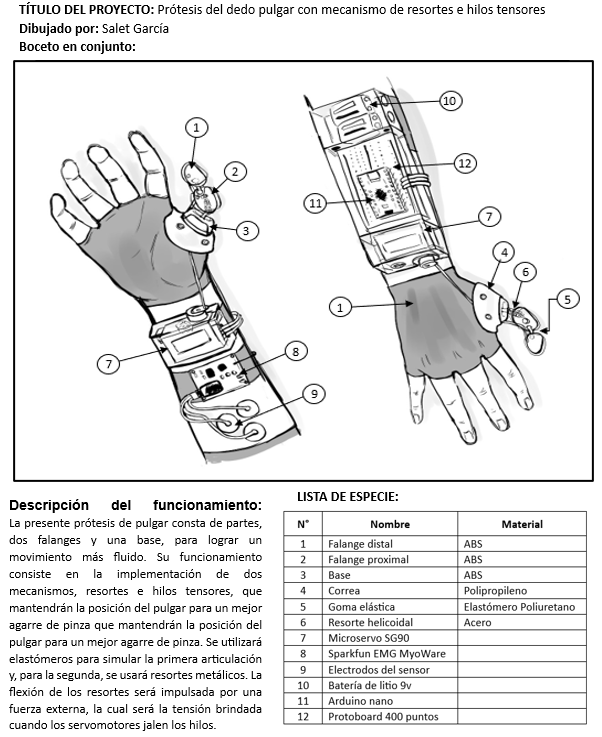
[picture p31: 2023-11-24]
Imágenes/Captura de pantalla 2023-10-17 214737.png

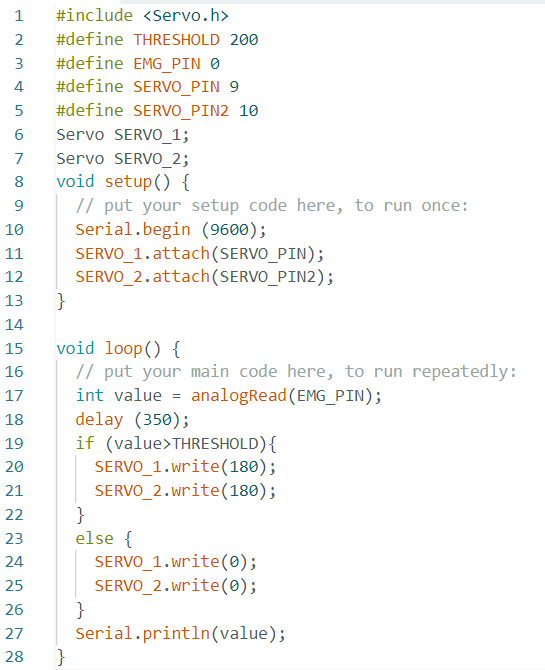
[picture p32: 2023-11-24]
Imágenes/Código Rafita.png

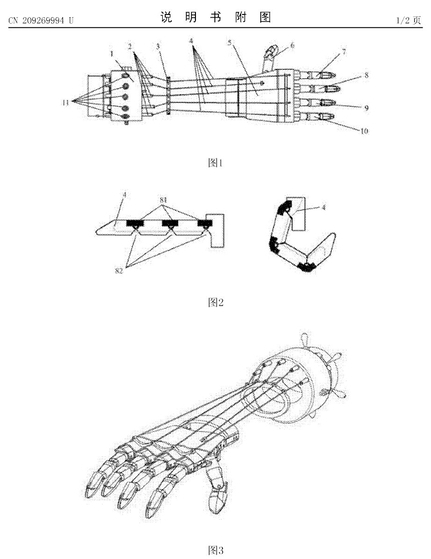
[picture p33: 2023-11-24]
Imágenes/Patente mano antebrazo.jpeg

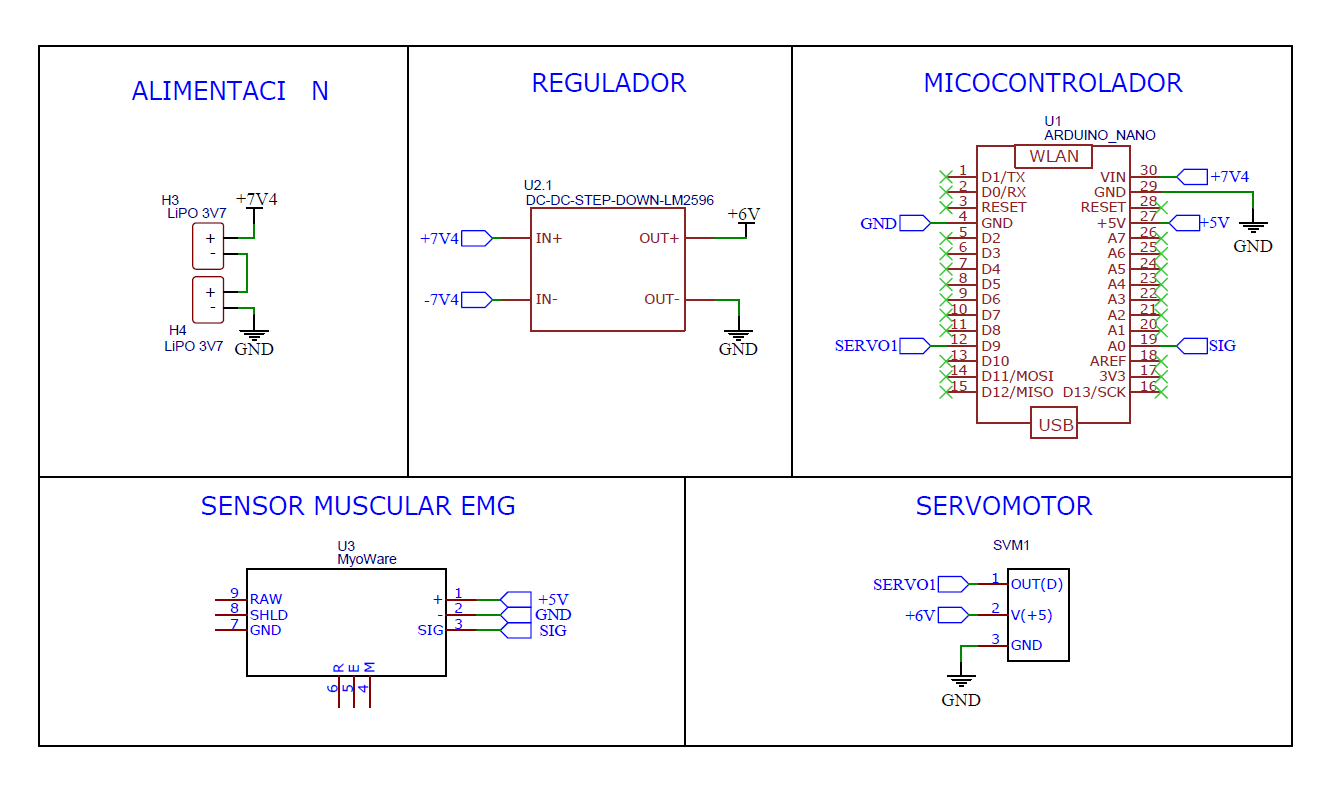
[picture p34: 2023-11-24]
Imágenes/Esquema circuito.png

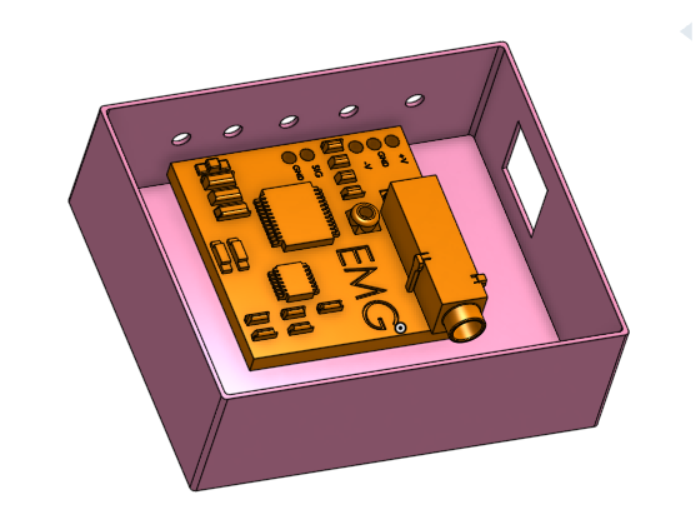
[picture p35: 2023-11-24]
Imágenes/Captura de pantalla 2023-10-20 030708.png

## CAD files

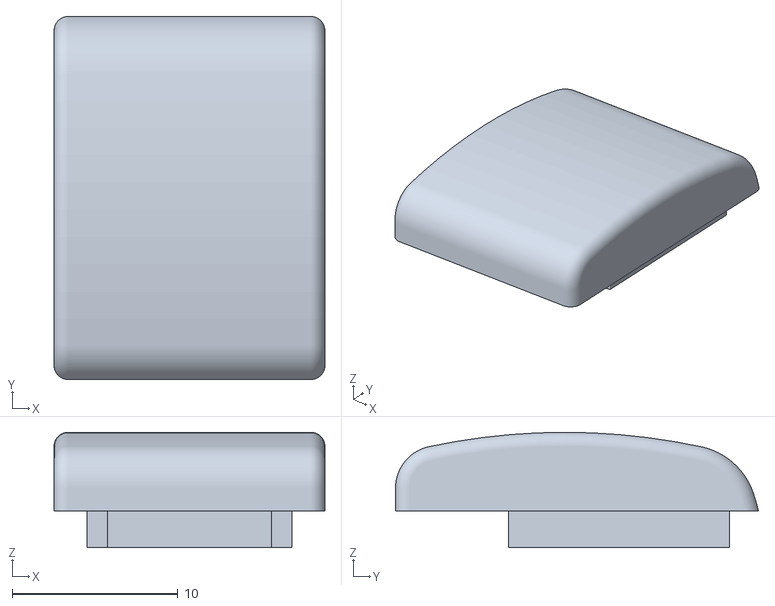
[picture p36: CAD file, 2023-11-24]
Modelado/Modelado de todas las piezas/Falange D - Part 2.stl
16.3 x 21.9 x 6.95

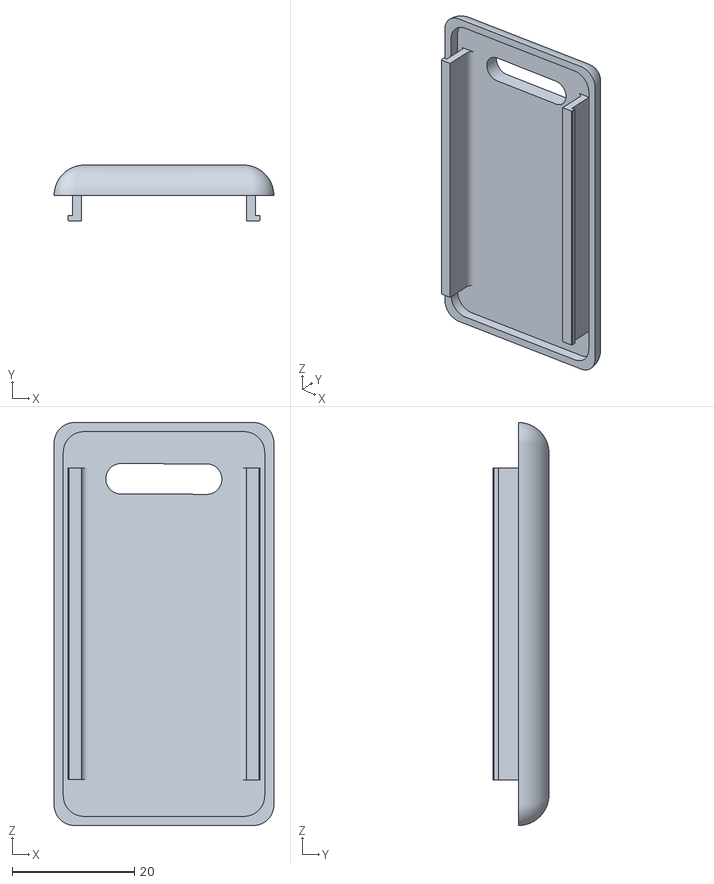
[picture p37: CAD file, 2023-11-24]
Modelado/Modelado de todas las piezas/Tapa sensor EMG.stl
36.0 x 9.15 x 66.0

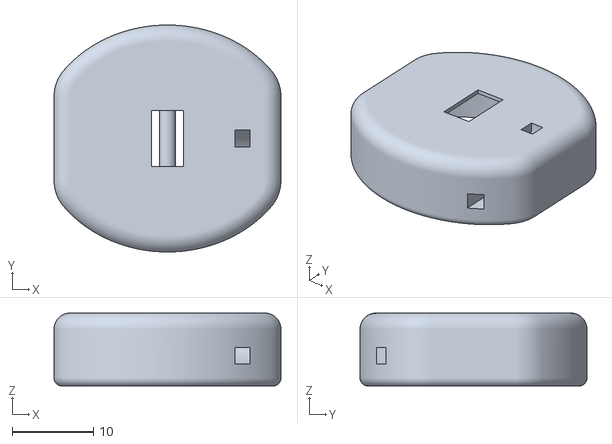
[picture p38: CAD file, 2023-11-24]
Modelado/Modelado de todas las piezas/Base dedo.stl
28.0 x 28.0 x 9.00

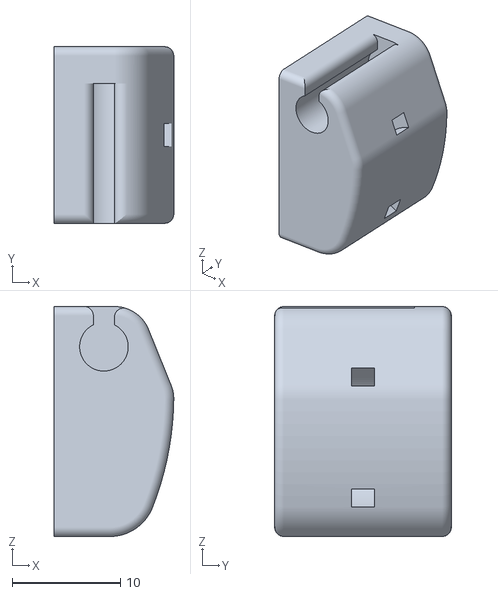
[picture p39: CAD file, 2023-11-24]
Modelado/Modelado de todas las piezas/Falange P - Part 2.stl
11.0 x 16.3 x 21.2

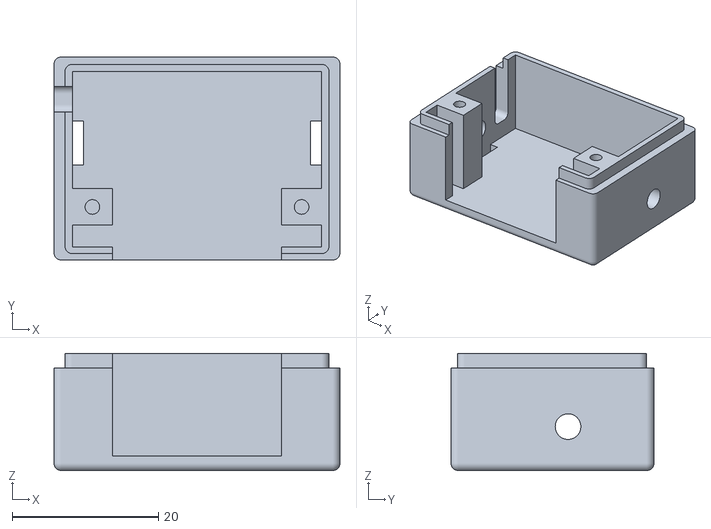
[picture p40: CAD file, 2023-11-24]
Modelado/Modelado de todas las piezas/Case Servo.stl
39.1 x 27.8 x 16.0

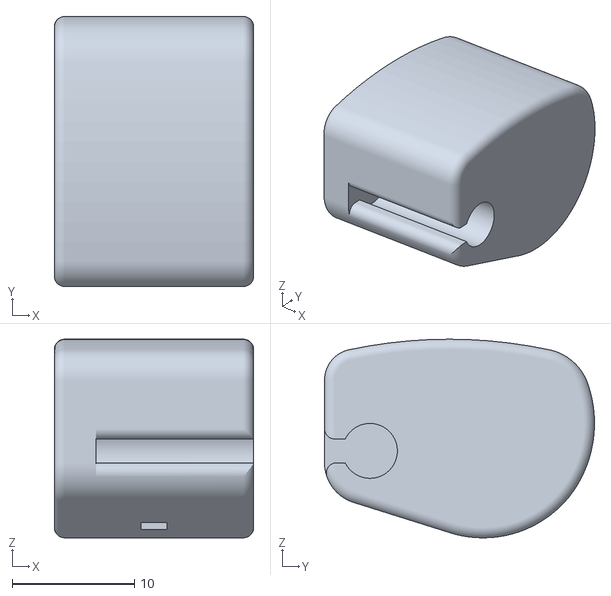
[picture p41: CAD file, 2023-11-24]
Modelado/Modelado de todas las piezas/Falange D Fin.stl
16.3 x 22.1 x 16.3

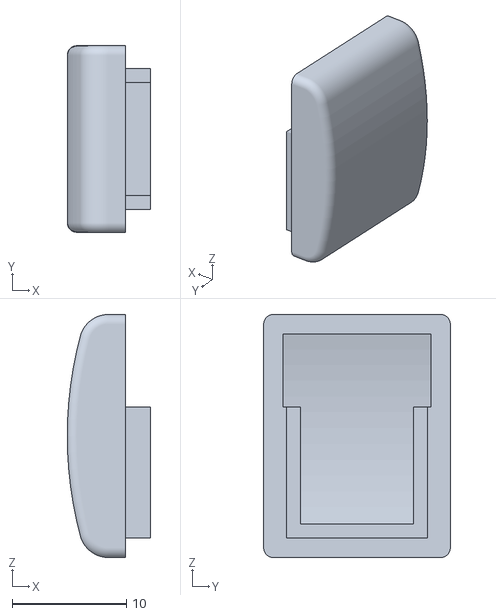
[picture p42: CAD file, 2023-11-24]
Modelado/Modelado de todas las piezas/Falange P - Part 1.stl
7.30 x 16.3 x 21.2

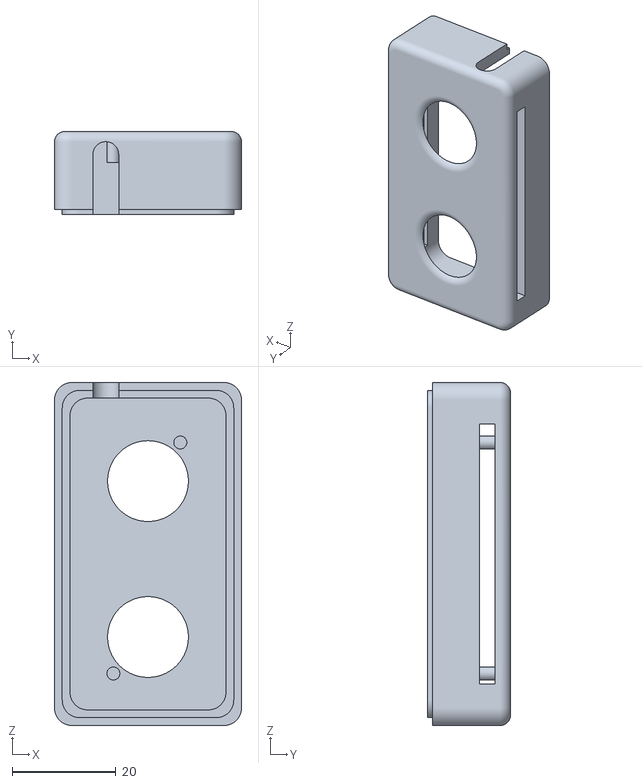
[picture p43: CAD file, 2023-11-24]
Modelado/Modelado de todas las piezas/CASE SENSOR EMG MYOWARE (1).stl
36.0 x 16.0 x 66.0

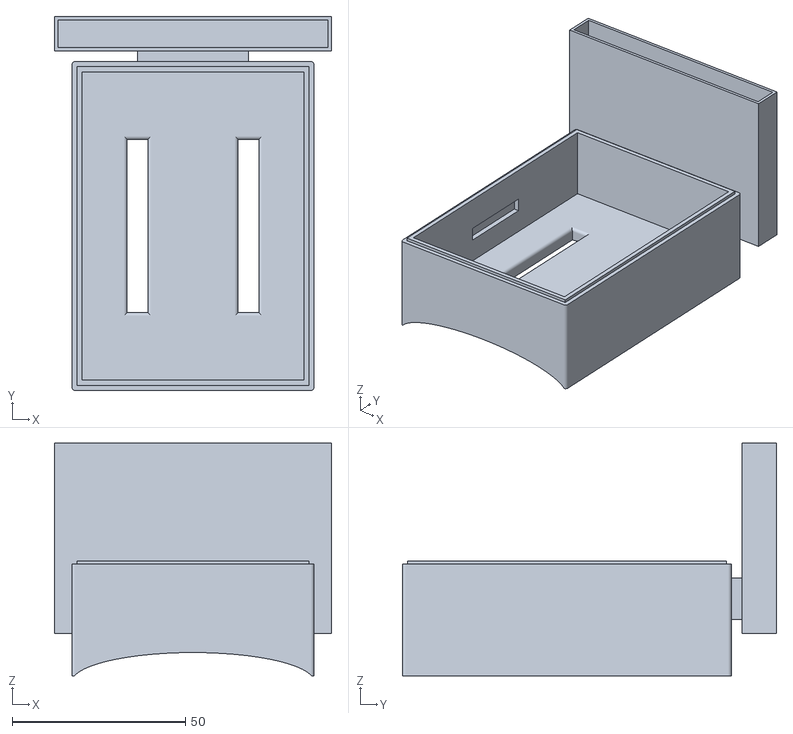
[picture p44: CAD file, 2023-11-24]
Modelado/Modelado de todas las piezas/Case Arduino.stl
80.0 x 108.0 x 67.3

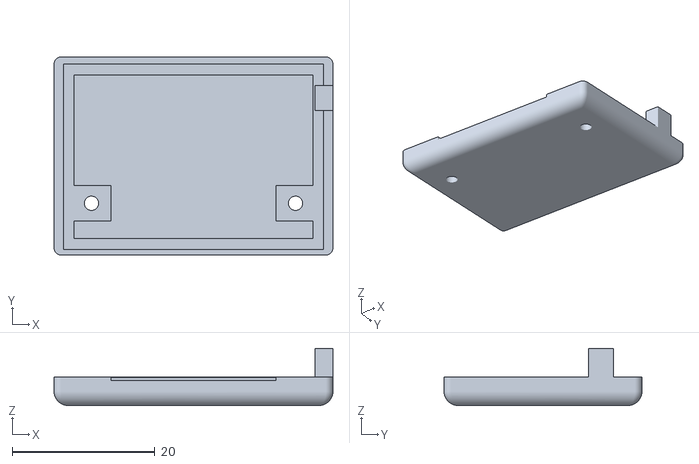
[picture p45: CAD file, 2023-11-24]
Modelado/Modelado de todas las piezas/Tapa del case servo.stl
39.1 x 27.8 x 8.00

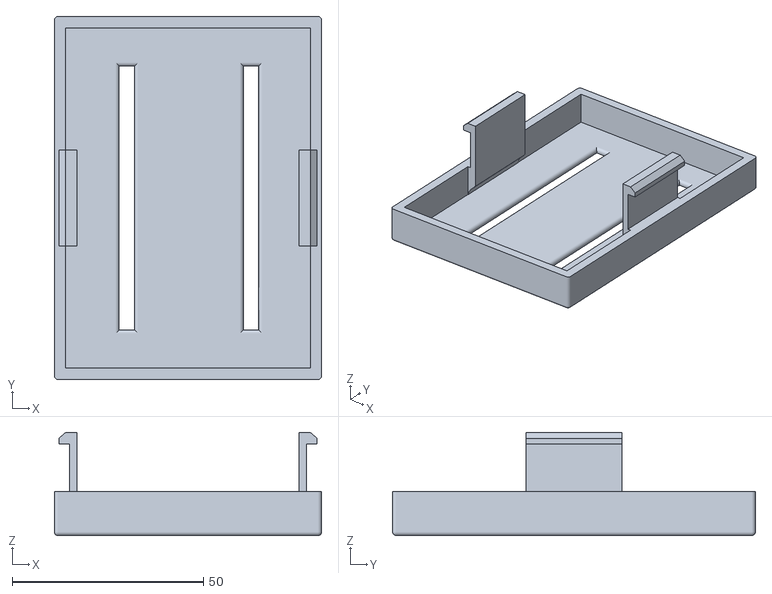
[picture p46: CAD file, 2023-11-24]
Modelado/Modelado de todas las piezas/Tapa Arduino.stl
70.0 x 95.0 x 27.0

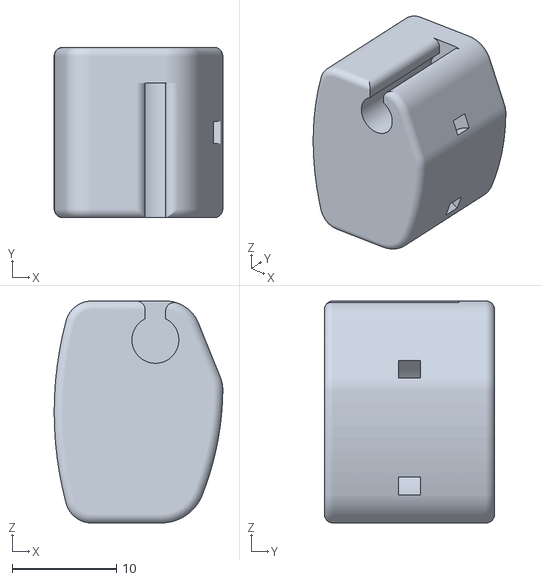
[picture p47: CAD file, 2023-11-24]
Modelado/Modelado de todas las piezas/Falange P Fin.stl
16.1 x 16.3 x 21.2

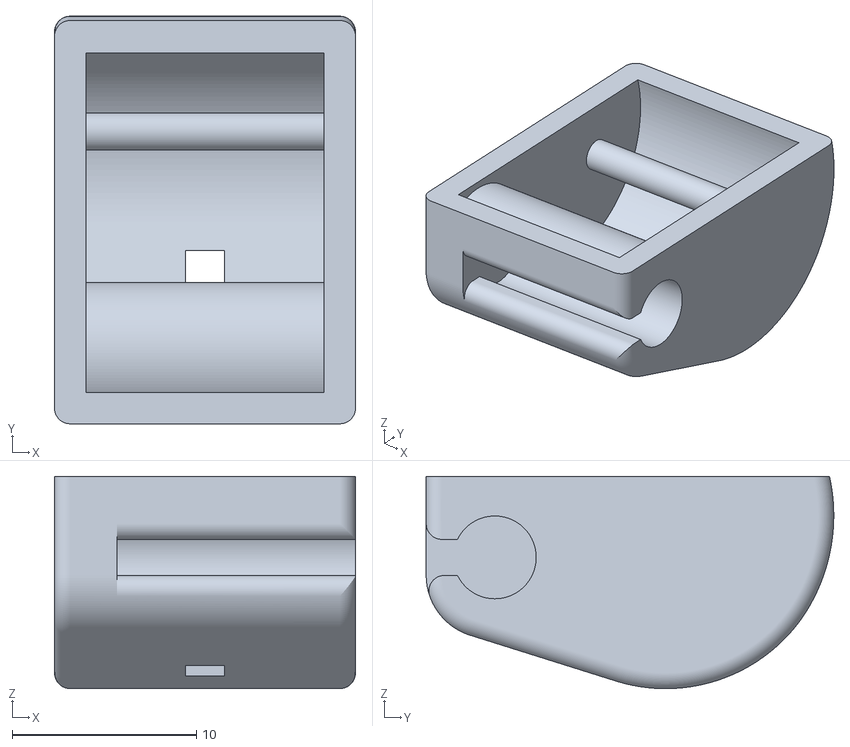
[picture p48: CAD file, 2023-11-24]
Modelado/Modelado de todas las piezas/Falange D - Part 1.stl
16.3 x 22.1 x 11.5

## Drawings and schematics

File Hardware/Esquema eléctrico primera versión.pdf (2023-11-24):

# MICOCONTROLADOR

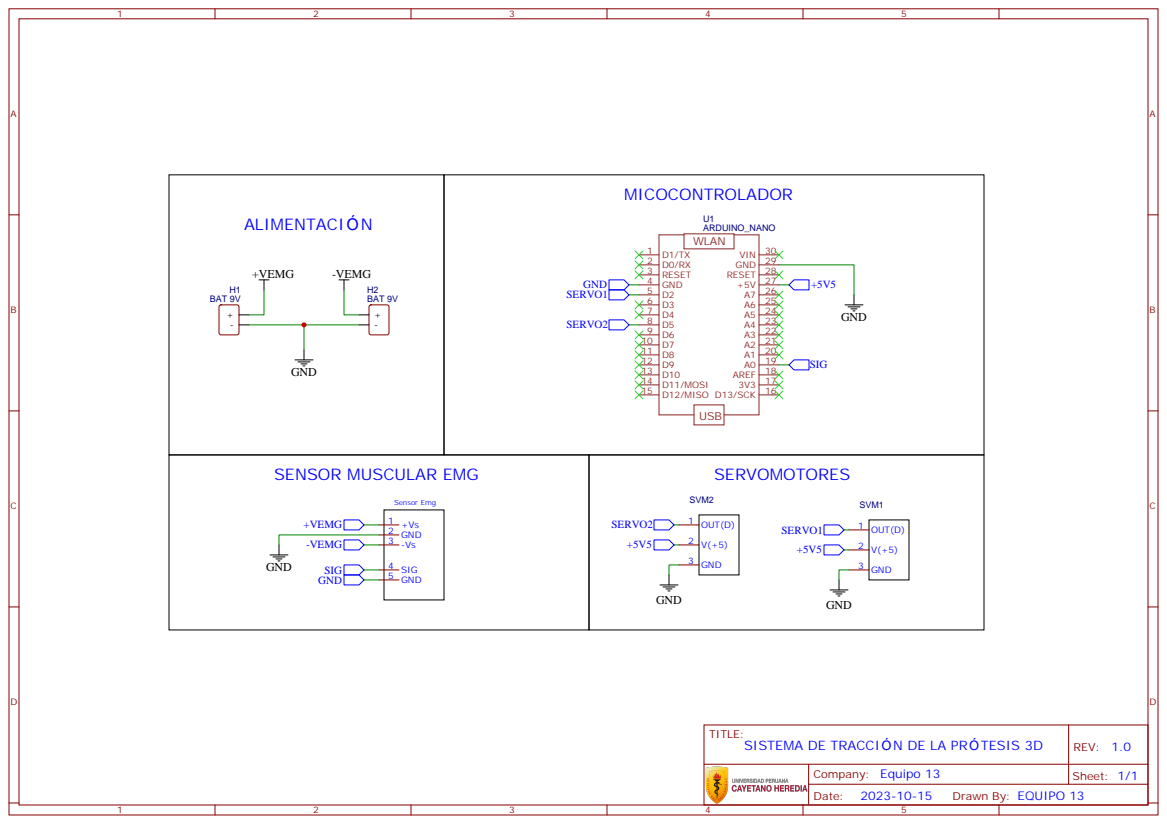
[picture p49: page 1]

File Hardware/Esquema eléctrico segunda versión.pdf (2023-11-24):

# MICOCONTROLADOR

# ALIMENTACI N

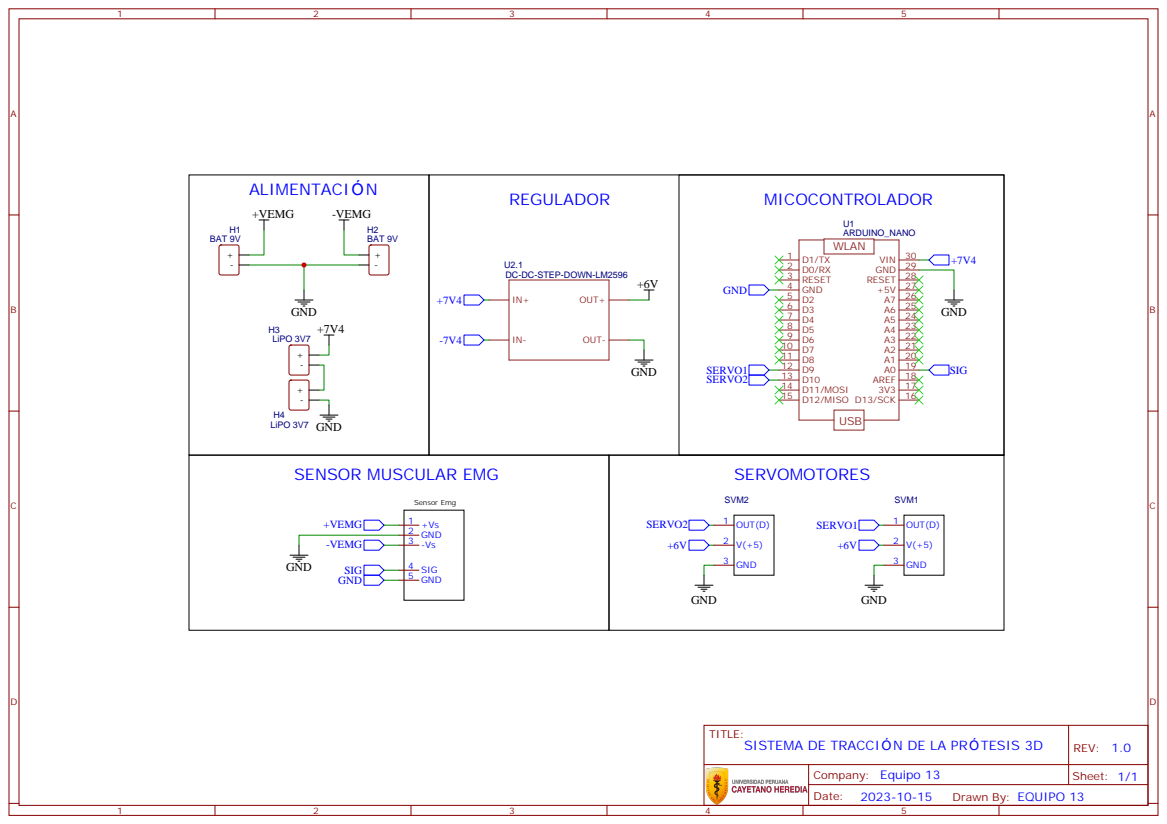
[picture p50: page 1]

DC-DC-STEP-DOWN-LM2596

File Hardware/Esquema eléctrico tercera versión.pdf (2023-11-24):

# MICOCONTROLADOR ALIMENTACI N

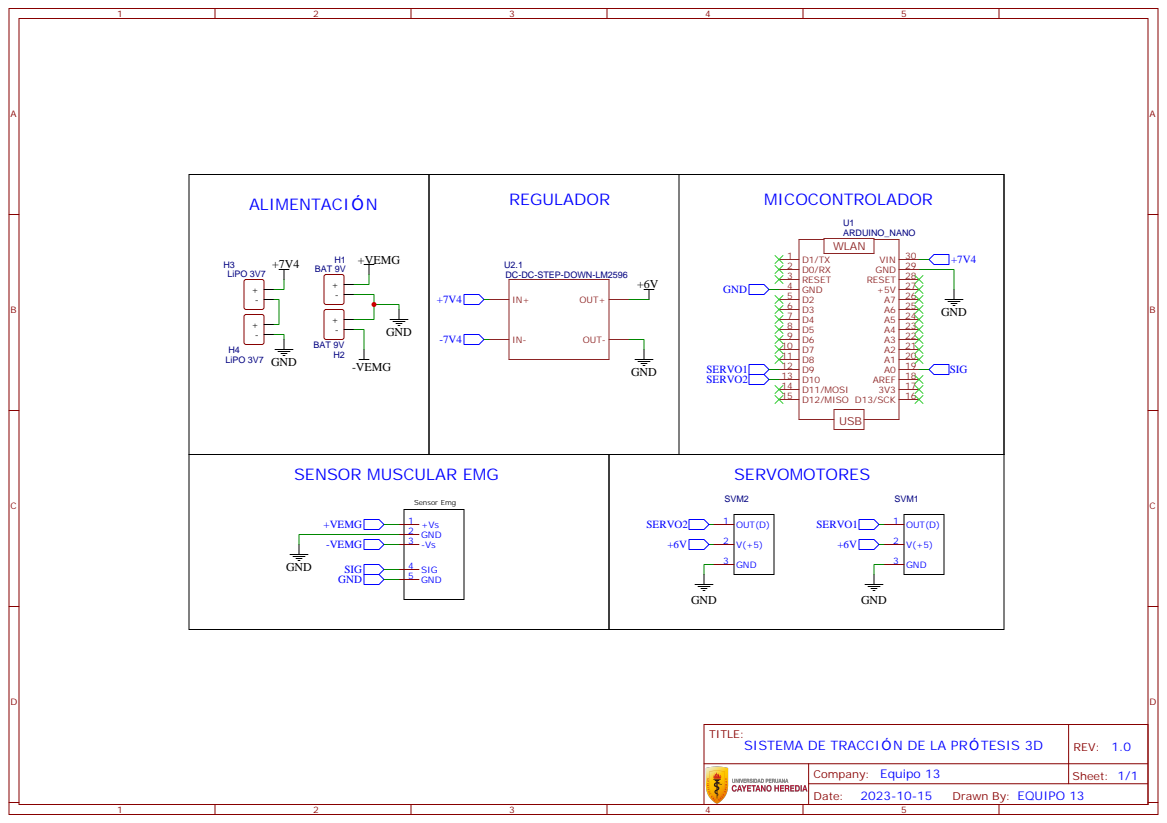
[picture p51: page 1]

DC-DC-STEP-DOWN-LM2596

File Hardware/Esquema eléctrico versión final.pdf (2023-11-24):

# MICOCONTROLADOR ALIMENTACIÓN

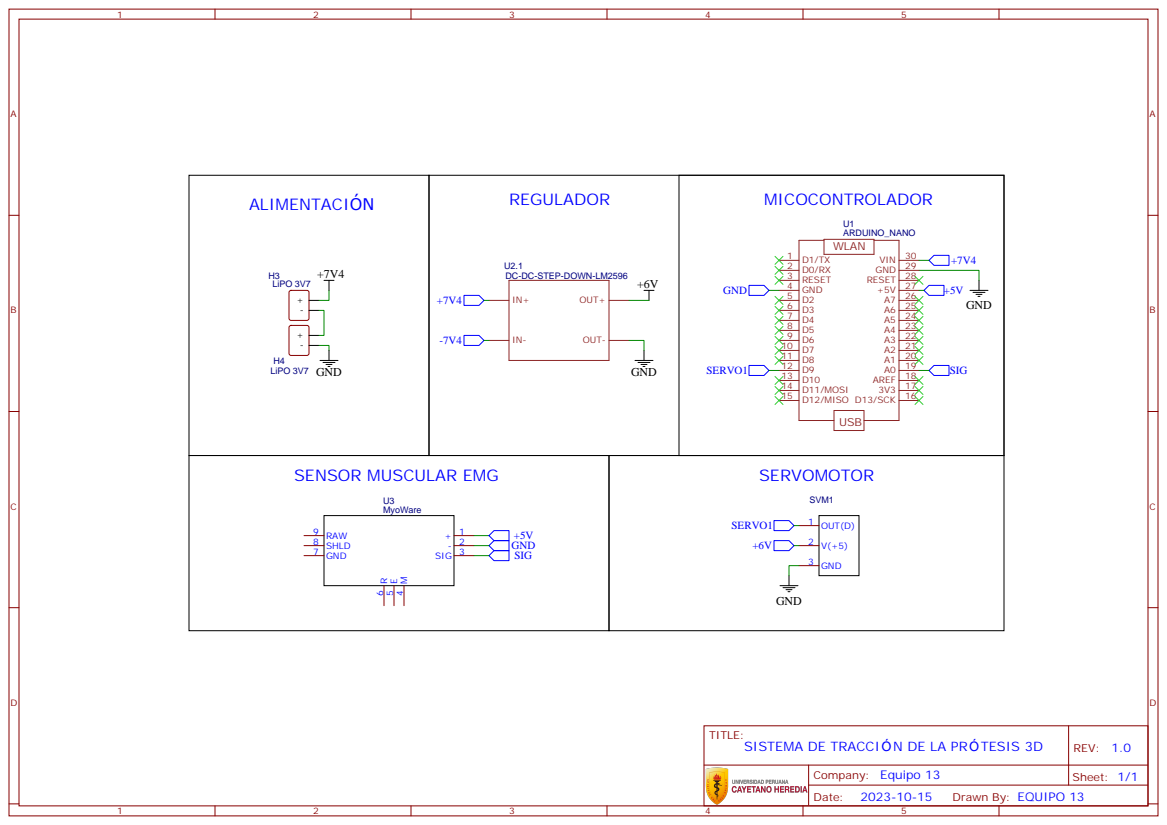
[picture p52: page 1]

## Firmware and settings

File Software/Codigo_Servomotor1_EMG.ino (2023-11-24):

#include <Servo.h>
#define THRESHOLD 300
#define EMG_PIN 0 
#define SERVO_PIN 9
Servo SERVO_1; 
void setup() {
  // put your setup code here, to run once:
  Serial.begin (9600);
  SERVO_1.attach(SERVO_PIN);
}

void loop() {
  // put your main code here, to run repeatedly:
  int value = analogRead(EMG_PIN);
  delay (400);
  if (value>THRESHOLD){
    SERVO_1.write(0);
  }
  else {
    SERVO_1.write(180);
  }
  Serial.println(value);
}
